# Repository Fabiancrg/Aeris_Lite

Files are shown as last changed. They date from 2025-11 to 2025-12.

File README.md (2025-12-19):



| Supported Targets | ESP32-C6 | ESP32-H2 |
| --- |  --- | --- |

# Zigbee Air Quality Sensor - Aeris




This project implements a Zigbee Router that reads air quality sensors and exposes them as standard Zigbee sensor endpoints with **real-time RGB LED visual indicators**.

## Key Features

✅ **7 Zigbee Endpoints**: Temperature, Humidity, Pressure, VOC Index, NOx Index, CO2, LED Config, Status LED  
✅ **4 High-Precision Sensors**: SHT45, LPS22HB, SGP41, SCD40  
✅ **4 RGB Status LEDs**: Independent visual feedback for CO2, VOC, NOx, and Humidity  
✅ **Configurable Thresholds**: Adjust warning/danger levels via Zigbee2MQTT  
✅ **Zigbee Router**: Can accept other devices (max 10 children)  
✅ **OTA Support**: Firmware updates over Zigbee  
✅ **Factory Reset**: Boot button for easy network reset

## Hardware Requirements

- ESP32-C6 development board (or compatible)
- Air quality sensors:
  - **SHT45 Temperature and Humidity sensor** via I2C
  - **LPS22HB Pressure sensor** via I2C
  - **SGP41 VOC and NOx sensor** via I2C
  - **SCD40 CO2 sensor** via I2C
- **5× SK6812/WS2812B RGB LEDs** in daisy-chain configuration (air quality visual indicators)
  - Single GPIO20 with SN74AHCT1G125 buffer for all LEDs
  - LED chain: CO2 → VOC → NOx → Humidity → Status
- I2C connection (SDA/SCL pins configurable)
- **Power supply**: 5V USB, 500mA minimum recommended

## Features

The Zigbee air quality sensor exposes the following sensor endpoints:

### Endpoint 1: Temperature and Humidity Sensor
- **Temperature Measurement Cluster (0x0402)**: Temperature in °C
- **Relative Humidity Measurement Cluster (0x0405)**: Humidity in %
- **Sensor**: Sensirion SHT45 (I2C)
- **Temperature Range**: -40°C to +125°C
- **Temperature Accuracy**: ±0.1°C (typical, 15-40°C)
- **Humidity Range**: 0-100% RH
- **Humidity Accuracy**: ±1.0% RH (typical, 25-75% RH)
- **Measurement Time**: 8.2ms (high precision mode)
- **Conversion**: Temperature: T = -45 + 175×(S/65535), Humidity: RH = -6 + 125×(S/65535)
- **Calibration Offsets**: Custom attributes (0xF010, 0xF011) for temperature/humidity adjustment
- **Sensor Refresh Interval**: Configurable update rate (10-3600s, default 30s) via attribute 0xF012

### Endpoint 2: Pressure Sensor
- **Pressure Measurement Cluster (0x0403)**: Atmospheric pressure in hPa
- **Sensor**: STMicroelectronics LPS22HB (I2C)
- **Update Rate**: On-demand (one-shot mode for power savings)
- **Range**: 260-1260 hPa
- **Accuracy**: ±0.025 hPa (typical)
- **Measurement Time**: ~15ms per reading

### Endpoint 3: VOC Index Sensor
- **Analog Input Cluster (0x000C)**: VOC Index (1-500)
- **Sensor**: Sensirion SGP41 (I2C)
- **Description**: Volatile Organic Compounds air quality index
- **Raw signals**: VOC raw values available
- **Update Rate**: 1 Hz enforced (minimum 1-second interval per datasheet)
- **Note**: Requires temperature/humidity compensation from SHT45

### Endpoint 4: NOx Index Sensor
- **Analog Input Cluster (0x000C)**: NOx Index (1-500)
- **Sensor**: Sensirion SGP41 (I2C)
- **Description**: Nitrogen Oxides air quality index
- **Raw signals**: NOx raw values available
- **Update Rate**: 1 Hz enforced (minimum 1-second interval per datasheet)
- **Note**: Requires temperature/humidity compensation from SHT45

### Endpoint 5: CO2 Sensor
- **CO2 Concentration Cluster (0x040D)**: Carbon dioxide in ppm
- **Sensor**: Sensirion SCD40 (I2C)
- **Range**: 400-2000 ppm (optimized for indoor air quality)
- **Accuracy**: ±(40 ppm + 5% of reading)
- **Update Rate**: 5 seconds (automatic periodic measurement)
- **Pressure Compensation**: Automatic compensation using LPS22HB pressure data
- **Calibration**: Automatic self-calibration (ASC) disabled for stable baseline in controlled environments
- **Additional**: Built-in temperature and humidity sensor (bonus)

### Endpoint 6: LED Configuration
- **On/Off Cluster (0x0006)**: Master switch to enable/disable all RGB status LEDs
- **Custom Attributes (0xF000-0xF00C)**: Configurable air quality thresholds and individual LED control
- **Bitmask Control (0xF00C)**: Individual enable/disable for each of the 4 LEDs
- **Thresholds**: Adjustable orange/red warning levels for VOC, NOx, CO2, Humidity

### Endpoint 7: Status LED
- **On/Off Cluster (0x0006)**: Enable/disable Zigbee status LED
- **Automatic Status Indication**: Shows Zigbee network connection status
  - 🟢 **Green**: Successfully connected to coordinator
  - 🟡 **Blinking Green/Orange**: Joining network
  - 🟠 **Orange**: Not joined to network
  - 🔴 **Red**: Error during initialization
- **GPIO**: GPIO8 (built-in LED on ESP32-C6 Supermini)

### RGB LED Air Quality Indicators

The device includes **4 separate RGB LEDs (SK6812)** that provide real-time visual feedback for air quality:

### LED Indicators
- **CO2 LED** (GPIO1): Shows carbon dioxide level status
- **VOC LED** (GPIO18): Shows volatile organic compounds status
- **NOx LED** (GPIO15): Shows nitrogen oxides status
- **Humidity LED** (GPIO14): Shows humidity level status

### Color Coding
Each LED independently displays:
- 🟢 **Green**: Parameter is in good/healthy range
- 🟠 **Orange**: Parameter is not ideal (warning level)
- 🔴 **Red**: Parameter is poor/unhealthy (danger level)

### Features
- **Independent operation**: Each LED shows only its corresponding sensor
- **At-a-glance status**: Quickly identify which parameter needs attention
- **Configurable thresholds**: Adjust warning/danger levels via Zigbee2MQTT
- **Brightness control**: Adjustable LED brightness (1-255) via Level Control cluster
- **Settings persistence**: All LED settings, thresholds, and calibrations stored in NVS (survive reboots)
- **Dual control**:
  - **Master switch**: Enable/disable all sensor LEDs at once (On/Off cluster)
  - **Individual control**: Enable/disable each LED separately via bitmask (0xF00C)
  - **Status LED control**: Independent on/off control for Zigbee status LED (endpoint 10)
- **Low power**: LEDs only update when color changes

### LED Control

**Master On/Off Switch:**
- Turn all LEDs on/off regardless of individual settings
- Located in On/Off cluster (standard Zigbee)

**Individual LED Bitmask (0xF00C):**
- Control each LED independently using a single 8-bit value
- Each bit represents one LED (1=enabled, 0=disabled)
- Bit assignments:
  - Bit 0 (0x01): CO2 LED
  - Bit 1 (0x02): VOC LED
  - Bit 2 (0x04): NOx LED
  - Bit 4 (0x10): Humidity LED
- Default: `0x17` (all LEDs enabled)

**Examples:**
```
0x17 (23)  - All LEDs enabled
0x03 (3)   - Only CO2 and VOC enabled
0x04 (4)   - Only NOx enabled
0x05 (5)   - CO2 and NOx enabled
0x00 (0)   - All LEDs disabled (individual level)
```

### Default Thresholds (all configurable)
- **VOC Index**: Orange ≥150, Red ≥250
- **NOx Index**: Orange ≥150, Red ≥250
- **CO2**: Orange ≥1000 ppm, Red ≥1500 ppm
- **Humidity**: Orange <30% or >70%, Red <20% or >80%

See [LED Configuration Guide](LED_CONFIGURATION.md) for detailed setup and usage.

## I2C and UART Configuration

### I2C Bus (Temperature, Humidity, Pressure, VOC, CO2)

The device communicates with most sensors via I2C:

- **SDA Pin**: GPIO 6 (configurable in `aeris_driver.h`)
- **SCL Pin**: GPIO 7 (configurable in `aeris_driver.h`)
- **Frequency**: 100 kHz
- **Pull-ups**: Internal pull-ups enabled

**I2C Addresses:**
- SHT45 (Temp/Humidity): 0x44 (fixed address)
- LPS22HB (Pressure): 0x5C (default, SA0=0) or 0x5D (SA0=1)
- SGP41 (VOC/NOx): 0x59 (fixed address)
- SCD40 (CO2): 0x62 (fixed address)

## Project Structure

```
Aeris_zb/
├── main/
│   ├── esp_zb_aeris.c         # Main Zigbee application
│   ├── esp_zb_aeris.h         # Zigbee configuration header
│   ├── aeris_driver.c         # Air quality sensor driver implementation
│   ├── aeris_driver.h         # Sensor driver header
│   ├── led_indicator.c        # RGB LED driver (6 LEDs via RMT)
│   ├── led_indicator.h        # LED driver header
│   ├── settings.c             # NVS settings persistence
│   ├── settings.h             # Settings header
│   ├── esp_zb_ota.c           # OTA update support
│   ├── esp_zb_ota.h           # OTA header
│   ├── board.h                # Board pin definitions (GPIO mapping)
│   ├── CMakeLists.txt         # Component build configuration
│   └── idf_component.yml      # Component dependencies
├── CMakeLists.txt             # Project CMakeLists
├── sdkconfig                  # ESP-IDF configuration
├── README.md                  # This file
├── LED_CONFIGURATION.md   # LED setup and Zigbee2MQTT integration
├── LED_IMPLEMENTATION.md  # LED technical implementation details
└── ENDPOINT_MAP.md        # Complete Zigbee endpoi
```

## Building and Flashing

1. Set up ESP-IDF v5.5.1 or later
2. Configure the project:
   ```bash
   idf.py set-target esp32c6
   idf.py menuconfig
   ```
3. Build the project:
   ```bash
   idf.py build
   ```
4. Flash to device:
   ```bash
   idf.py -p COMx flash monitor
   ```

## Configuration

### Zigbee Configuration

The device is configured as a Zigbee Router:
- **Endpoints**: 1-7 (sensor data + LED configuration + status LED)
  - Endpoints 1-5: Sensor data (Temperature, Humidity, Pressure, VOC, NOx, CO2)
  - Endpoint 6: Air quality LED configuration and control
  - Endpoint 7: Zigbee status LED control
- **Profile**: Home Automation (0x0104)
- **Device IDs**: Various sensor types + On/Off output for LED control
- **Channel Mask**: All channels
- **Max Children**: 10 (router can accept other devices)

### LED Configuration

**Air Quality LEDs (4 LEDs)** - Configure via Zigbee2MQTT endpoint 6:
- **Master On/Off**: Single switch to enable/disable all LEDs (On/Off cluster)
- **Individual Control**: Bitmask attribute (0xF00C) for per-LED enable/disable
  - Set to `0x17` (23) for all LEDs
  - Set to `0x03` (3) for CO2 + VOC only
  - Set to `0x00` (0) to disable all (at individual level)
- **Thresholds**: 8 configurable attributes (VOC, NOx, CO2, Humidity orange/red levels)
- **GPIO Pins**: Configurable in `main/board.h` (defaults: GPIO1, 18, 15, 14)

**Control Logic:**
- Master OFF → All LEDs off (ignores bitmask)
- Master ON + bit set → LED shows sensor status color
- Master ON + bit clear → LED off

**Zigbee Status LED (1 LED)** - Configure via Zigbee2MQTT endpoint 7:
- **On/Off Control**: Enable/disable status LED
- **Automatic Status Indication**:
  - 🟢 **Green**: Successfully connected to Zigbee coordinator
  - 🟡 **Blinking Green/Orange**: Actively joining network (searching for coordinator)
  -  **Orange**: Not joined to any network or left the network (idle)
  - 🔴 **Red**: Error during initialization or join failed
- **GPIO Pin**: GPIO23 (configurable in `main/board.h`)
- **Blink Pattern**: 500ms interval during network join process

See [LED Configuration Guide](LED_CONFIGURATION.md) for detailed threshold settings.

### Sensor Configuration

Configure sensor I2C addresses and settings in `aeris_driver.c`:
- Default I2C pins: SDA=GPIO6, SCL=GPIO7
- Adjust pins in `aeris_driver.h` if needed

### Joining the Network

On first boot, the device will automatically enter network steering mode. Once joined, the device will save the network credentials and automatically rejoin on subsequent boots.

## Usage

### From Zigbee Coordinator (e.g., Zigbee2MQTT, Home Assistant)

1. Put your coordinator in pairing mode
2. Power on the ESP32-C6 device
3. Wait for the device to join (check logs - status LED will turn green when connected)
4. The air quality sensor will appear with the following entities:
   - Temperature (°C)
   - Humidity (%)
   - Pressure (hPa)
   - VOC Index (1-500)
   - NOx Index (1-500)
   - CO2 (ppm)
   - **Air Quality LED Master Switch** (On/Off - controls all 4 air quality LEDs)
   - **LED Enable Mask** (0-15 - individual LED control)
   - **LED Thresholds** (configurable warning/danger levels)
   - **Status LED Switch** (On/Off - controls Zigbee status LED)

### LED Control Examples

**Via Zigbee2MQTT:**

```javascript
// Turn all sensor LEDs on (master switch)
await publish('zigbee2mqtt/aeris/set', {state: 'ON'});

// Turn all sensor LEDs off (master switch)
await publish('zigbee2mqtt/aeris/set', {state: 'OFF'});

// Set LED brightness (1-255, default 128)
await publish('zigbee2mqtt/aeris/set', {brightness: 128});
await publish('zigbee2mqtt/aeris/set', {brightness: 255});  // Max brightness
await publish('zigbee2mqtt/aeris/set', {brightness: 64});   // Dim

// Enable all 4 LEDs individually (bitmask)
await publish('zigbee2mqtt/aeris/set', {led_enable_mask: 15});  // 0x0F

// Enable only CO2 and VOC LEDs
await publish('zigbee2mqtt/aeris/set', {led_enable_mask: 3});   // 0x03

// Enable only NOx LED
await publish('zigbee2mqtt/aeris/set', {led_enable_mask: 4});   // 0x04

// Enable CO2, VOC, and Humidity LEDs
await publish('zigbee2mqtt/aeris/set', {led_enable_mask: 11});  // 0x0B

// Disable all LEDs via bitmask (master can still be ON)
await publish('zigbee2mqtt/aeris/set', {led_enable_mask: 0});

// Status LED control (endpoint 10)
await publish('zigbee2mqtt/aeris_status/set', {state: 'ON'});   // Enable status LED
await publish('zigbee2mqtt/aeris_status/set', {state: 'OFF'});  // Disable status LED

// Calibration offsets (stored in NVS)
await publish('zigbee2mqtt/aeris/set', {temperature_offset: 5});   // +0.5°C
await publish('zigbee2mqtt/aeris/set', {temperature_offset: -10}); // -1.0°C
await publish('zigbee2mqtt/aeris/set', {humidity_offset: 20});     // +2.0% RH

// Sensor refresh interval (10-3600 seconds, default 30)
await publish('zigbee2mqtt/aeris/set', {sensor_refresh_interval: 60}); // 1 minute
```

### Visual LED Status

**Air Quality LEDs (4 RGB LEDs)** provide real-time visual feedback:
- **CO2 LED**: Green/Orange/Red based on CO2 levels
- **VOC LED**: Green/Orange/Red based on VOC Index
- **NOx LED**: Green/Orange/Red based on NOx Index
- **Humidity LED**: Green/Orange/Red based on humidity range

**Status LED (1 RGB LED)** shows Zigbee network state:
- 🟢 **Green**: Connected to coordinator
- 🟡 **Blinking Green/Orange**: Joining network (searching)
- 🟠 **Orange**: Not joined or left network (idle)
- 🔴 **Red**: Join failed or error state (will retry)

**At a glance**, you can see:
- All green (air quality) = Excellent air quality
- Mixed colors = Some parameters need attention
- Status LED solid green = Device is online and connected
- Status LED blinking = Device is trying to join network
- Red LEDs = Immediate action needed (ventilate, increase/decrease humidity, etc.)

Configure thresholds in Zigbee2MQTT to match your preferences. See [LED Configuration Guide](LED_CONFIGURATION.md).

### Sensor Reading Updates

- Sensors are polled periodically (configurable interval)
- Values are reported to the Zigbee coordinator when they change
- All endpoints support binding and reporting configuration

## Supported Sensors

This project provides a framework for air quality sensors. You'll need to implement the actual sensor drivers:

### Temperature/Humidity
- **SHT45** (implemented): Sensirion high-precision sensor
  - I2C interface (address 0x44)
  - Temperature: -40 to +125°C, ±0.1°C accuracy
  - Humidity: 0-100% RH, ±1.0% RH accuracy
  - High repeatability mode: 8.2ms measurement time
  - CRC-8 checksum for data integrity
  - Serial number readout
  - Soft reset command
  - Low power: 0.4 µA idle
- **Alternative**: SHT4x series, BME280, DHT22

### Pressure
- **LPS22HB** (implemented): STMicroelectronics MEMS pressure sensor
  - I2C interface (address 0x5C or 0x5D)
  - Measures 260-1260 hPa
  - ±0.025 hPa accuracy
  - Internal temperature sensor (bonus)
  - Low power: 3 µA @ 1Hz
  - Configurable output rate (1-75 Hz)
- **Alternative**: BMP280, BME280 (Bosch sensors)

### VOC and NOx Index
- **SGP41** (implemented): Sensirion VOC and NOx sensor
  - I2C interface (address 0x59)
  - Dual gas sensing: VOC + NOx
  - Separate Zigbee endpoints for VOC (endpoint 6) and NOx (endpoint 7)
  - Raw signal output (requires algorithm)
  - Temperature/humidity compensation
  - Built-in heater for measurement
  - Low power: 2.6 mA average @ 1Hz
  - Serial number readout
  - Self-test capability
- **Note**: Full Gas Index Algorithm integration recommended for production
- **Alternative**: SGP40 (VOC only), BME680 (combo sensor)

### CO2
- **SCD40** (implemented): Sensirion NDIR CO2 sensor
  - I2C interface (address 0x62)
  - Range: 400-2000 ppm (indoor air quality)
  - Accuracy: ±(40 ppm + 5%)
  - Automatic periodic measurement every 5 seconds
  - **Ambient pressure compensation** from LPS22HB sensor
  - Built-in temperature and humidity sensor
  - Automatic self-calibration (ASC)
  - CRC-8 data validation
  - Serial number readout
  - Low power: 15 mA average @ 1 measurement/5s
- **Alternative**: SCD41 (extended range 400-5000 ppm)

## Implementation Notes

The `aeris_driver.c` file contains:

1. **SHT45 implementation** (complete):
   - I2C initialization and device detection
   - Soft reset on startup
   - Serial number readout and verification
   - High repeatability measurement mode
   - CRC-8 validation on all data
   - Temperature and humidity conversion
   - Humidity clamping to 0-100% range

2. **LPS22HB implementation** (complete):
   - I2C initialization and device detection
   - WHO_AM_I verification (0xB1)
   - 25 Hz output data rate
   - Block data update enabled
   - Pressure reading in hPa
   - Temperature reading included

4. **SGP41 implementation** (complete):
   - I2C initialization and device detection
   - Serial number readout and verification
   - Self-test execution
   - Raw VOC and NOx signal measurement
   - Separate VOC and NOx index reporting (endpoints 6 and 7)
   - Temperature/humidity compensation support
   - CRC8 validation on all data
   - Placeholder index calculation (needs Gas Index Algorithm)

5. **SCD40 implementation** (complete):
   - I2C initialization and device detection
   - Serial number readout and verification
   - Automatic periodic measurement mode
   - CO2, temperature, and humidity reading
   - Ambient pressure compensation using LPS22HB data
   - CRC-8 validation on all data
   - Data ready status checking
   - 5-second measurement interval

## Sensor Wiring Diagrams

### SHT45 Wiring

```
SHT45 Pin → ESP32-C6
VDD       → 3.3V
GND       → GND
SCL       → GPIO 7
SDA       → GPIO 6
```

**Note**: SHT45 operates at 3.3V. No level shifters needed with ESP32-C6.

### LPS22HB Wiring

```
LPS22HB Pin → ESP32-C6
VDD         → 3.3V
GND         → GND
SCL         → GPIO 7 (I2C SCL)
SDA         → GPIO 6 (I2C SDA)
SA0         → GND (for address 0x5C) or 3.3V (for 0x5D)
```

**Note**: LPS22HB operates at 1.7-3.6V. Use 3.3V supply.

### SGP41 Wiring

```
SGP41 Pin → ESP32-C6
VDD       → 3.3V
GND       → GND
SCL       → GPIO 7 (I2C SCL)
SDA       → GPIO 6 (I2C SDA)
```

**Note**: SGP41 operates at 1.7-3.6V. Use 3.3V supply. No external pull-ups needed on most breakout boards.

### SCD40 Wiring

```
SCD40 Pin → ESP32-C6
VDD       → 3.3V
GND       → GND
SCL       → GPIO 7 (I2C SCL)
SDA       → GPIO 6 (I2C SDA)
```

**Note**: SCD40 operates at 2.4-5.5V. Use 3.3V supply. Automatic periodic measurement every 5 seconds. Benefits from ambient pressure compensation provided by LPS22HB sensor.

### SK6812 RGB LED Wiring (5 LEDs)

The device uses 5 separate RGB LEDs for visual air quality feedback:

```
LED Purpose    GPIO    Connection
━━━━━━━━━━━━━━━━━━━━━━━━━━━━━━━━━━━━━━━
CO2 LED        1       Data line
VOC LED        18      Data line
NOx LED        15      Data line
Humidity LED   14      Data line
Status LED     8       Data line (Zigbee status)

For each LED:
  Data → GPIO pin (see table above)
  VCC  → 5V (SK6812 specification)
  GND  → GND
```

**Notes**: 
- SK6812 LEDs use WS2812 protocol via RMT peripheral
- Each LED operates independently showing its sensor's status
- All 5 sensor LEDs can be enabled/disabled together via Zigbee (endpoint 9)
- Status LED controlled separately via endpoint 10
- Brightness adjustable 1-255 via Level Control cluster
- GPIO pins are configurable in `main/board.h`
- Total LED current (all 6 at max brightness): ~360mA

**Color Codes**:
- 🟢 Green = Good air quality for that parameter
- 🟠 Orange = Warning level (not ideal)
- 🔴 Red = Danger level (poor air quality)

See [LED Configuration Guide](LED_CONFIGURATION.md) for threshold configuration via Zigbee2MQTT.

### Important: Gas Index Algorithm

The SGP41 currently uses a **simplified placeholder** for VOC/NOx index calculation. For production use, integrate Sensirion's **Gas Index Algorithm**:

- Download from: https://github.com/Sensirion/gas-index-algorithm
- Provides proper VOC Index (1-500) and NOx Index (1-500)
- Requires learning period (~10 minutes for VOC, ~12 hours for NOx)
- Handles baseline tracking and auto-calibration

## Troubleshooting

### Sensors not responding
- **I2C sensors**:
  - Verify I2C wiring (SDA/SCL connections)
  - Check I2C pull-up resistors (usually 4.7kΩ)
  - Verify sensor power supply (3.3V for SHT45, LPS22HB, SGP41, SCD40)
  - Use `i2cdetect` to scan for sensor addresses
  - Monitor I2C traffic in logs
  - **SHT45**: Read serial number to verify communication
  - **SHT45**: Check CRC errors in logs
  - **LPS22HB**: Check WHO_AM_I register (should be 0xB1)
  - **LPS22HB**: Verify address 0x5C or 0x5D (depends on SA0 pin)
  - **SGP41**: Check serial number readout
  - **SGP41**: Verify self-test passes (result 0xD400)
  - **SGP41**: Ensure temperature/humidity data is available for compensation
  - **SCD40**: Check serial number readout
  - **SCD40**: Verify data ready status (measurements every 5 seconds)
  - **SCD40**: Check CRC errors in logs

**Power Note**: 
- **5 LEDs** (4 air quality + 1 status) at full brightness: ~300mA
- **ESP32-C6 + sensors**: ~50-80mA
- **Total**: ~350-380mA
- **Recommended power supply**: 500mA minimum (USB 5V)

### Build errors
- Make sure ESP-IDF v5.5.1+ is installed
- Run `idf.py fullclean` and rebuild
- Check that all sensor libraries are in `idf_component.yml`

---

## 🙌 Credits

- Zigbee2MQTT ecosystem: [Koenkk/zigbee2mqtt](https://github.com/Koenkk/zigbee2mqtt) and [zigbee-herdsman-converters](https://github.com/Koenkk/zigbee-herdsman-converters)
- Base Zigbee framework: Espressif ESP-IDF examples

## 🛡️ License

This repository uses multiple licenses depending on content type:

- **Code** (`*.c`, `*.h`, `*.yaml`) — [GNU GPLv3](./LICENSE)  
- **PCB files** (`*.zip`, `*.json`) — [CC BY-NC-SA 4.0](./LICENSE-hardware)

---

## ⚠️ Disclaimer

This project is provided as-is, without any warranty or guarantee of fitness for a particular purpose. Use at your own risk. The authors and contributors are not responsible for any damage, malfunction, or loss resulting from the use, modification, or installation of this hardware or software.

- This is an open-source, community-driven project intended for educational and experimental use.
- The hardware and firmware are not certified for commercial or safety-critical applications.
- Always follow proper electrical safety procedures when working with sensors and embedded systems.
- Modifying or installing this project may void your equipment warranty.
- Ensure compliance with local laws and regulations regarding wireless devices.

By using this project, you acknowledge and accept these terms.

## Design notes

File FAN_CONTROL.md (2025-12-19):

# Fan Control System - Aeris Lite

## Overview

The Aeris Lite includes an intelligent fan control system to improve sensor accuracy by managing airflow across the sensors. This is especially important because some sensors (SGP41, SCD40) generate heat during operation which can affect temperature and humidity readings.

## Hardware Setup

### Components Required

- **Fan**: 5V 4-wire PWM fan (25mm, 30mm, or 40mm)
  - Recommended: Dual ball bearing type for reliability
  - Example: Sunon MF25100V1-1000U-A99 or similar
- **MOSFET**: IRLML6344TRPBF (N-channel, SOT-23)
- **Diode**: N5819HW1-7-F (1A Schottky, SOD-123)
- **Resistor**: 10kΩ (0603/0805 SMD)

### Circuit Diagram

```
              5V Supply
                 │
              [Fan Motor]
                 │
         ┌──[N5819HW1-7-F]──┐  Flyback protection diode
         │   (Schottky)      │  (Cathode to 5V, Anode to Drain)
         │                   │
    [Drain]                  │
         │                   │
   IRLML6344TRPBF            │
         │                   │
    [Gate]────[10kΩ]─────────┘  Pull-down resistor
         │                   
GPIO5 (3.3V)                   Power control
         │                   
    [Source]                 
         │                   
        GND                  

Fan 4-Wire Connections:
  Red/Yellow → 5V (through MOSFET)
  Black      → GND
  Blue       → GPIO6 (PWM speed control)
  Yellow     → GPIO7 (TACH feedback)
```

### GPIO Pin Assignments

| Function | GPIO | Direction | Description |
|---|---|---|---|
| Fan Power | GPIO5 | Output | N-MOSFET gate (ON/OFF control) |
| Fan PWM | GPIO6 | Output | PWM signal (25kHz, 0-100% duty) |
| Fan TACH | GPIO7 | Input | Tachometer pulses (RPM monitoring) |

## Features

### 1. PWM Speed Control
- **Frequency**: 25kHz (standard for PC fans)
- **Resolution**: 8-bit (0-255 duty cycle)
- **Speed Range**: 0-100%
- **Minimum Speed**: 20% (fans typically don't start below this)

### 2. RPM Monitoring
- Real-time RPM measurement via tachometer
- 2 pulses per revolution (standard)
- Blocking measurement (~1 second)
- Health monitoring and fault detection

### 3. Operating Modes
- **OFF** (0%): Fan completely stopped
- **LOW** (30%): Quiet operation, minimal airflow
- **MEDIUM** (60%): Balanced airflow and noise
- **HIGH** (100%): Maximum airflow
- **AUTO**: Adaptive speed based on sensor readings

### 4. Adaptive Control
Automatically adjusts fan speed based on:
- **Temperature**: Higher temps → faster fan
- **VOC Index**: Poor air quality → faster fan
- **Thresholds**:
  - T > 35°C or VOC > 300 → HIGH (100%)
  - T > 30°C or VOC > 200 → MEDIUM (60%)
  - T > 25°C or VOC > 150 → LOW (30%)
  - Otherwise → OFF (0%)

### 5. Health Monitoring
- Detects fan stall/failure (RPM < 100)
- Verifies fan starts when commanded
- Can trigger alerts or fallback behavior

## Software API

### Initialization

```c
#include "fan_control.h"

// Initialize fan control (call once at startup)
esp_err_t ret = fan_init();
if (ret != ESP_OK) {
    ESP_LOGE("APP", "Fan init failed");
}
```

### Basic Control

```c
// Set fan speed (0-100%)
fan_set_speed(50);  // 50% speed

// Power control
fan_set_power(true);   // Turn on
fan_set_power(false);  // Turn off

// Predefined modes
fan_set_mode(FAN_MODE_LOW);     // 30%
fan_set_mode(FAN_MODE_MEDIUM);  // 60%
fan_set_mode(FAN_MODE_HIGH);    // 100%
fan_set_mode(FAN_MODE_OFF);     // 0%
```

### RPM Monitoring

```c
// Get current RPM (blocks for ~1 second)
uint32_t rpm = fan_get_rpm();
ESP_LOGI("APP", "Fan RPM: %lu", rpm);

// Quick check (uses last reading)
bool running = fan_is_running();
if (!running) {
    ESP_LOGW("APP", "Fan not running!");
}

// Get full status
fan_status_t status;
fan_get_status(&status);
ESP_LOGI("APP", "Enabled: %d, Speed: %d%%, RPM: %lu, Running: %d, Fault: %d",
         status.enabled, status.speed_percent, status.rpm, 
         status.running, status.fault);
```

### Advanced: Adaptive Control

```c
// In your main measurement loop:
void sensor_measurement_task(void *pvParameters) {
    while (1) {
        float temp = read_temperature();
        uint16_t voc = read_voc_index();
        
        // Automatically adjust fan speed
        fan_adaptive_control(temp, voc);
        
        vTaskDelay(pdMS_TO_TICKS(30000));  // Every 30s
    }
}
```

### Health Check Example

```c
// Set speed and verify fan starts
esp_err_t ret = fan_control_with_check(60);
if (ret == ESP_FAIL) {
    ESP_LOGE("APP", "Fan failed to start - check hardware!");
    // Could trigger alarm, LED indicator, etc.
}
```

## Integration with Aeris Driver

The fan control is automatically initialized in `aeris_driver_init()` and starts at low speed (30%) by default. This provides continuous gentle airflow for accurate sensor readings while keeping noise low.

To enable adaptive control, modify your measurement loop:

```c
aeris_sensor_state_t state;
aeris_get_sensor_data(&state);

// Adaptive fan control based on readings
fan_adaptive_control(state.temperature_c, state.voc_index);
```

## Zigbee Integration (Future Enhancement)

The fan control can be exposed via Zigbee custom attributes:

```c
/* Proposed custom attributes for fan control */
#define ATTR_FAN_ENABLED      0xF030  // bool - Fan power ON/OFF
#define ATTR_FAN_SPEED        0xF031  // uint8 - Speed percentage (0-100)
#define ATTR_FAN_MODE         0xF032  // uint8 - Mode (0=OFF, 1=LOW, 2=MED, 3=HIGH, 4=AUTO)
#define ATTR_FAN_RPM          0xF033  // uint32 - Current RPM (read-only)
#define ATTR_FAN_STATUS       0xF034  // uint8 - Status (0=Off, 1=Running, 2=Fault)
```

This would allow control via Home Assistant/Zigbee2MQTT:
- Enable/disable fan remotely
- Adjust speed percentage
- Select operating mode
- Monitor RPM and health status

## Troubleshooting

### Fan Doesn't Start
1. Check 5V power supply (adequate current)
2. Verify GPIO connections (GPIO5, GPIO6, GPIO7)
3. Check MOSFET soldering (IRLML6344TRPBF)
4. Verify diode polarity (N5819HW1-7-F)
5. Try higher speed: `fan_set_speed(50)` or more
6. Check fan minimum starting speed (usually 20-30%)

### Fan Runs But No RPM Reading
1. Verify TACH wire connected to GPIO7
2. Check pull-up enabled (automatic in code)
3. Confirm fan has 4 wires (TACH output)
3-wire fans don't have TACH
4. Try different fan (some cheap fans have fake TACH)

### Fan Too Noisy
1. Reduce speed: `fan_set_speed(30)` or lower
2. Check fan quality (dual ball bearing are quieter long-term)
3. Verify fan is mounted securely (vibration causes noise)
4. Consider larger fan at lower RPM (40mm vs 25mm)

### Sensors Still Show Self-Heating
1. Increase fan speed: `fan_set_speed(60)`
2. Check airflow path (ensure air reaches sensors)
3. Verify fan is drawing air across sensors
4. Use temperature offset calibration (existing feature)
5. Consider enclosure ventilation holes

### Fan Runs at Full Speed Always
1. Check PWM wire connected to GPIO6 (not 5V)
2. Verify fan supports PWM control (4-wire)
3. Check PWM signal with oscilloscope (25kHz)
4. Try different GPIO if interference suspected

## Power Consumption

| Mode | Fan Speed | Typical Current | Power |
|---|---|---|---|
| OFF | 0% | 0mA | 0W |
| LOW | 30% | 40-60mA | 0.2-0.3W |
| MEDIUM | 60% | 80-100mA | 0.4-0.5W |
| HIGH | 100% | 120-150mA | 0.6-0.75W |

**Note**: Power consumption varies by fan model. Larger fans draw more current.

## PCB Layout Recommendations

1. **Trace widths**: 
   - 5V power to fan: 20-30 mil (0.5-0.76mm)
   - GPIO signals: 10 mil (0.25mm) minimum
   
2. **Component placement**:
   - Place MOSFET and diode close to fan connector
   - Keep PWM trace short to reduce EMI
   
3. **Ground plane**: 
   - Connect MOSFET source directly to ground plane
   - Use thermal relief for easy soldering
   
4. **Thermal considerations**:
   - No heatsink needed for IRLML6344TRPBF (<1mW dissipation)
   - Keep away from hot components if possible

## Performance Impact

### With Fan (Recommended)
- ✅ Temperature accuracy: ±0.2°C
- ✅ Humidity accuracy: ±1%RH
- ✅ Fast response time (<30s)
- ✅ Representative sampling
- ⚠️ Additional power: ~0.2-0.5W
- ⚠️ Slight noise (dependent on speed)

### Without Fan
- ⚠️ Temperature error: +2-4°C (self-heating)
- ⚠️ Humidity affected by temperature error
- ⚠️ Slow response time (>2 min)
- ⚠️ Stagnant air (non-representative)
- ✅ Lower power consumption
- ✅ Silent operation

## Conclusion

The fan control system significantly improves sensor accuracy for the Aeris Lite by managing self-heating effects and ensuring representative air sampling. The adaptive control automatically balances performance, accuracy, and noise based on environmental conditions.

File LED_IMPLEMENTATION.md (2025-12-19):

# RGB LED Implementation Summary

## Overview
Successfully implemented **5 SK6812/WS2812B RGB LEDs in daisy-chain configuration** on a single GPIO with configurable air quality thresholds via Zigbee2MQTT. Each sensor parameter (CO2, VOC, NOx, Humidity) has its own dedicated LED indicator, plus a separate **status LED** for network/firmware state.

## Architecture Changes (v2.0)

### Hardware Simplification
**Previous (v1.0):** 5 separate GPIOs (GPIO1, GPIO18, GPIO15, GPIO14, GPIO8) with 74AHCT244 driver
**Current (v2.0):** Single GPIO20 with SN74AHCT1G125 buffer, 5 LEDs in daisy-chain

**Benefits:**
- Saves 4 GPIOs for other peripherals
- Simpler PCB routing (single data line)
- More efficient RMT usage (1 channel instead of 5)
- Synchronized LED updates (all LEDs refresh at once)
- Single point buffer/level shifter

### LED Daisy-Chain Order
```
GPIO20 → Buffer → [CO2] → [VOC] → [NOx] → [Humidity] → [Status]
                   Pos0     Pos1    Pos2      Pos3         Pos4
```

## Files Created/Modified

### New Files
1. **main/led_indicator.h** - LED driver API for 6 independent LEDs
2. **main/led_indicator.c** - SK6812 RMT driver with 6-channel support
3. **doc/LED_CONFIGURATION.md** - Complete user documentation for LED configuration

### Modified Files
1. **main/board.h** - Added 6 LED GPIO pin definitions:
   - CO2: GPIO21
   - VOC: GPIO4
   - NOx: GPIO8
   - PM2.5: GPIO5
   - Humidity: GPIO10
   - Status: GPIO23 (network/firmware status indicator)
2. **main/esp_zb_aeris.h** - Added:
   - LED configuration endpoint (endpoint 8)
   - 12 custom attribute IDs for thresholds (0xF000-0xF00B)
3. **main/esp_zb_aeris.c** - Added:
   - LED driver include
   - LED initialization in deferred_driver_init()
   - Endpoint 8 creation with On/Off + custom threshold attributes
   - Attribute handler for LED configuration changes
   - LED update call in sensor_update_zigbee_attributes()
4. **main/CMakeLists.txt** - Added esp_driver_rmt dependency

## Features Implemented

### Hardware
- **6 separate SK6812 RGB LEDs** using ESP32-C6 RMT peripheral
- Each LED on dedicated GPIO (GPIO21, GPIO4, GPIO8, GPIO5, GPIO10, GPIO23)
- **6 independent RMT channels** for simultaneous control (5 parameter LEDs + 1 status)
- Three color states per LED: Green (good), Orange (warning), Red (danger)
- Efficient RMT encoding for precise SK6812 timing

### Zigbee Integration
- **Endpoint 8**: LED Configuration
   - **Single On/Off cluster** for global enable/disable of all parameter LEDs (CO2, VOC, NOx, PM2.5, Humidity)
   - Analog Output cluster containing 12 custom threshold attributes
   - All parameter thresholds configurable via Zigbee2MQTT

### Threshold Parameters
All configurable via Zigbee attributes:

**VOC Index:**
- Orange threshold: 150 (default)
- Red threshold: 250 (default)

**CO2 (ppm):**
- Orange threshold: 1000 (default)
- Red threshold: 1500 (default)

**Humidity (%):**
- Orange low: 30% (default) - too dry warning
- Orange high: 70% (default) - too humid warning
- Red low: 20% (default) - too dry danger
- Red high: 80% (default) - too humid danger

**PM2.5 (µg/m³):**
- Orange threshold: 25 (default)
- Red threshold: 55 (default)

**NOx (ppb):**
- Orange threshold: 200 (default)
- Red threshold: 400 (default)

### LED Behavior
- **Each sensor has its own dedicated LED** showing independent status
- Evaluates sensors every 30 seconds
- **CO2 LED**: Shows CO2 level (green/orange/red based on CO2 thresholds)
- **VOC LED**: Shows VOC Index (green/orange/red based on VOC thresholds)
- **NOx LED**: Shows NOx level (green/orange/red based on NOx thresholds)
- **PM2.5 LED**: Shows particulate matter (green/orange/red based on PM2.5 thresholds)
- **Humidity LED**: Shows humidity level (green/orange/red based on humidity thresholds)
- **Status LED**: Shows network/firmware status (joining, connected, error) — behavior controlled by firmware, not thresholds
- **Single On/Off control** disables/enables all parameter LEDs; the status LED may remain active for critical network indicators depending on configuration
- Only updates each LED when its color changes (reduces RMT traffic)

## Default Thresholds Rationale

### VOC Index (Sensirion SGP41)
- 0-150: Good air quality → **Green**
- 151-250: Moderate, not ideal → **Orange**
- 251-500: Poor air quality → **Red**

### CO2 Levels
- 400-1000 ppm: Normal indoor → **Green**
- 1001-1500 ppm: Needs ventilation → **Orange**
- 1501+ ppm: Poor ventilation → **Red**

### Humidity
- 30-70%: Comfort zone → **Green**
- 20-30% or 70-80%: Outside comfort → **Orange**
- <20% or >80%: Health/mold risk → **Red**

### PM2.5 (EPA AQI)
- 0-25 µg/m³: Good/Moderate → **Green**
- 26-55 µg/m³: Unhealthy for sensitive → **Orange**
- 56+ µg/m³: Unhealthy → **Red**

## Usage Example

### From Zigbee2MQTT:
```json
# Enable all LEDs
{"led_enabled": true}

# Disable all LEDs
{"led_enabled": false}

# Adjust CO2 thresholds for stricter monitoring
{"co2_orange_threshold": 800, "co2_red_threshold": 1200}

# Make humidity range wider (20-75% before warning)
{"humidity_orange_low": 20, "humidity_orange_high": 75}
```

### In Home Assistant:
All thresholds appear as `number` entities. The single `switch.aeris_led_enabled` controls all parameter LEDs together (CO2, VOC, NOx, PM2.5, Humidity); the status LED behavior is firmware-controlled.

### LED Status Display:
With 4 separate LEDs, you can see the status of all parameters at a glance:
- All green = Excellent air quality across all parameters
- Mixed colors = Some parameters need attention
- Individual LED shows specific problem (e.g., red CO2 LED = ventilation needed)

## Testing Checklist
- [ ] Build project with `idf.py build`
- [ ] Flash to ESP32-C6
- [ ] Verify all 6 LEDs initialize (check serial logs)
- [ ] Pair with Zigbee coordinator
- [ ] Check that endpoint 8 appears in Zigbee2MQTT
- [ ] Test enabling/disabling all LEDs via On/Off attribute
- [ ] Adjust thresholds and verify appropriate LED changes color
- [ ] Test all 4 sensor thresholds independently:
  - [ ] VOC LED changes when VOC Index crosses thresholds
  - [ ] CO2 LED changes when CO2 crosses thresholds
  - [ ] Humidity LED changes when humidity crosses thresholds
  - [ ] PM2.5 LED changes when PM2.5 crosses thresholds
- [ ] Verify each LED operates independently

## Troubleshooting

**LEDs don't light:**
- Check GPIO wiring (GPIO21, GPIO4, GPIO8, GPIO5, GPIO10, GPIO23)
- Verify LED power supply for all 4 LEDs
- Check serial logs for RMT initialization errors
- Ensure LEDs are enabled (On/Off = true)

**Only some LEDs work:**
- Check individual GPIO connections
- Verify all 4 RMT channels initialized in logs
- Test each LED individually

**Can't change thresholds:**
- Verify endpoint 8 is exposed in Zigbee2MQTT
- Check custom attribute IDs are mapped correctly
- Try re-pairing device

**Wrong colors displayed:**
- Verify sensor readings are accurate (check sensor endpoints)
- Review threshold configuration for specific sensor
- Check logs for individual LED update messages

## Next Steps
1. Build and flash firmware
2. **Connect 4 SK6812 LEDs:**
   - CO2 LED → GPIO21
   - VOC LED → GPIO4
   - PM2.5 LED → GPIO5
   - Humidity LED → GPIO10
3. Pair with Zigbee coordinator
4. Configure thresholds in Zigbee2MQTT/Home Assistant
5. Fine-tune thresholds based on your environment
6. Observe each LED independently showing sensor status

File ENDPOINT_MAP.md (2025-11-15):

# Aeris_zb Endpoint Map

## Complete Endpoint Structure

```
┌─────────────────────────────────────────────────────────────────┐
│                     Aeris Air Quality Sensor                     │
│                      (Zigbee Router Device)                      │
└─────────────────────────────────────────────────────────────────┘

Endpoint 1: Temperature & Humidity
├─ Temperature Measurement (0x0402)
│  └─ Measured Value (int16, 0.01°C units)
├─ Relative Humidity Measurement (0x0405)
│  └─ Measured Value (uint16, 0.01% units)
└─ Basic, Identify clusters

Endpoint 2: Pressure
├─ Pressure Measurement (0x0403)
│  └─ Measured Value (int16, 0.1 hPa units)
└─ Basic, Identify clusters

Endpoint 3: PM1.0
├─ Analog Input (0x000C)
│  ├─ Present Value (float, µg/m³)
│  └─ Description: "PM1.0 µg/m³"
└─ Basic, Identify clusters

Endpoint 4: PM2.5
├─ Analog Input (0x000C)
│  ├─ Present Value (float, µg/m³)
│  └─ Description: "PM2.5 µg/m³"
└─ Basic, Identify clusters

Endpoint 5: PM10
├─ Analog Input (0x000C)
│  ├─ Present Value (float, µg/m³)
│  └─ Description: "PM10 µg/m³"
└─ Basic, Identify clusters

Endpoint 6: VOC Index
├─ Analog Input (0x000C)
│  ├─ Present Value (float, 1-500 index)
│  └─ Description: "VOC Index"
└─ Basic, Identify clusters

Endpoint 7: CO2
├─ Carbon Dioxide Measurement (0x040D)
│  ├─ Measured Value (float, ppm)
│  ├─ Min Measured Value: 400
│  └─ Max Measured Value: 5000
└─ Basic, Identify clusters

Endpoint 8: LED Configuration
├─ On/Off (0x0006)
│  └─ OnOff (bool) - Enable/disable LED
├─ Analog Output (0x000D) - Container for custom attributes
│  ├─ 0xF000: VOC Orange Threshold (uint16)
│  ├─ 0xF001: VOC Red Threshold (uint16)
│  ├─ 0xF002: CO2 Orange Threshold (uint16)
│  ├─ 0xF003: CO2 Red Threshold (uint16)
│  ├─ 0xF004: Humidity Orange Low (uint16)
│  ├─ 0xF005: Humidity Orange High (uint16)
│  ├─ 0xF006: Humidity Red Low (uint16)
│  ├─ 0xF007: Humidity Red High (uint16)
│  ├─ 0xF008: PM2.5 Orange Threshold (uint16)
│  └─ 0xF009: PM2.5 Red Threshold (uint16)
└─ Basic, Identify clusters
```

## Sensor Hardware

```
┌─────────────────────────────────────────────────────────────────┐
│                          I2C Bus (GPIO6/7)                       │
│                           100 kHz, 3.3V                          │
└─────────────────────────────────────────────────────────────────┘
    │
    ├─ SHT45 (0x44)      → Temperature & Humidity
    ├─ LPS22HB (0x5D)    → Pressure
    ├─ SGP41 (0x59)      → VOC Raw Signals → VOC Index
    └─ SCD40 (0x62)      → CO2

┌─────────────────────────────────────────────────────────────────┐
│                       UART (GPIO20, 9600)                        │
└─────────────────────────────────────────────────────────────────┘
    │
    └─ PMSA003A          → PM1.0, PM2.5, PM10

┌─────────────────────────────────────────────────────────────────┐
│                     RMT (4 channels, 10MHz)                      │
└─────────────────────────────────────────────────────────────────┘
    │
    ├─ SK6812 RGB LED (GPIO21)  → CO2 Level Indicator
    ├─ SK6812 RGB LED (GPIO4)   → VOC Index Indicator
    ├─ SK6812 RGB LED (GPIO5)   → PM2.5 Level Indicator
    └─ SK6812 RGB LED (GPIO10)  → Humidity Level Indicator
```

## Update Cycle

```
Every 30 seconds:
  ┌────────────────────────────────────────┐
  │ 1. Read all sensors                    │
  │    - SHT45: Temp, Humidity             │
  │    - LPS22HB: Pressure                 │
  │    - PMSA003A: PM1.0, PM2.5, PM10      │
  │    - SGP41: VOC Index                  │
  │    - SCD40: CO2                        │
  └────────────────────────────────────────┘
              ↓
  ┌────────────────────────────────────────┐
  │ 2. Update Zigbee attributes            │
  │    - Endpoints 1-7 sensor values       │
  └────────────────────────────────────────┘
              ↓
  ┌────────────────────────────────────────┐
  │ 3. Evaluate each LED independently     │
  │    - CO2 LED: Check CO2 vs thresholds  │
  │    - VOC LED: Check VOC vs thresholds  │
  │    - Hum LED: Check Hum vs thresholds  │
  │    - PM2.5 LED: Check PM vs thresholds │
  └────────────────────────────────────────┘
              ↓
  ┌────────────────────────────────────────┐
  │ 4. Update each LED color (if changed)  │
  │    - Each LED: Green/Orange/Red/Off    │
  └────────────────────────────────────────┘
```

## LED Color Logic (Per LED)

```
VOC LED:
  ┌─────────────────────────────────────────────────────────┐
  │ IF VOC >= voc_red_threshold           → RED             │
  │ ELSE IF VOC >= voc_orange_threshold   → ORANGE          │
  │ ELSE                                  → GREEN           │
  └─────────────────────────────────────────────────────────┘

CO2 LED:
  ┌─────────────────────────────────────────────────────────┐
  │ IF CO2 >= co2_red_threshold           → RED             │
  │ ELSE IF CO2 >= co2_orange_threshold   → ORANGE          │
  │ ELSE                                  → GREEN           │
  └─────────────────────────────────────────────────────────┘

Humidity LED (special case - range check):
  ┌─────────────────────────────────────────────────────────┐
  │ IF humidity <= hum_red_low OR >= hum_red_high → RED     │
  │ ELSE IF humidity <= hum_orange_low OR >= hum_orange_high│
  │                                           → ORANGE       │
  │ ELSE                                      → GREEN        │
  └─────────────────────────────────────────────────────────┘

PM2.5 LED:
  ┌─────────────────────────────────────────────────────────┐
  │ IF PM2.5 >= pm25_red_threshold        → RED             │
  │ ELSE IF PM2.5 >= pm25_orange_threshold → ORANGE         │
  │ ELSE                                  → GREEN           │
  └─────────────────────────────────────────────────────────┘

Global enable/disable:
  ┌─────────────────────────────────────────────────────────┐
  │ IF LED disabled via Zigbee     → ALL LEDs = OFF         │
  └─────────────────────────────────────────────────────────┘
```

## Zigbee2MQTT Device Structure

```json
{
  "ieee_address": "0x...",
  "friendly_name": "Aeris Air Quality Sensor",
  "model": "aeris-z",
  "vendor": "ESPRESSIF",
  "definition": {
    "endpoints": {
      "1": ["temperature", "humidity"],
      "2": ["pressure"],
      "3": ["pm1_0"],
      "4": ["pm2_5"],
      "5": ["pm10"],
      "6": ["voc_index"],
      "7": ["co2"],
      "8": ["led_config", "thresholds"]
    }
  }
}
```

## Pin Assignment Summary

| GPIO | Function | Device | Protocol |
|---|---|---|---|
| 3 | Antenna SEL0 | FM8625H | Digital Out |
| 4 | RMT Data | SK6812 VOC LED | RMT |
| 5 | RMT Data | SK6812 PM2.5 LED | RMT |
| 6 | I2C SDA | Sensors | I2C |
| 7 | I2C SCL | Sensors | I2C |
| 9 | Boot Button | Factory Reset | Digital In |
| 10 | RMT Data | SK6812 Humidity LED | RMT |
| 14 | Antenna SEL1 | FM8625H | Digital Out |
| 20 | UART RX | PMSA003A | UART |
| 21 | RMT Data | SK6812 CO2 LED | RMT |

## Power Budget (Estimated)

| Component | Current | Notes |
|---|---|---|
| ESP32-C6 | ~80mA | Active, Zigbee router |
| SHT45 | <0.5mA | Measurement mode |
| LPS22HB | <0.1mA | Low power mode |
| SGP41 | ~3mA | Active measurement |
| SCD40 | ~20mA | Active measurement |
| PMSA003A | ~100mA | Fan + laser active |
| SK6812 LEDs (×4) | ~240mA | Max brightness, all colors, all LEDs |
| **Total** | **~445mA** | Peak during measurement |

USB 5V supply required (min 1A recommended for margin).

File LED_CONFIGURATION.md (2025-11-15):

# RGB LED Air Quality Indicators

## Overview
The Aeris_zb air quality sensor includes **4 separate RGB LEDs (SK6812)** that provide independent visual feedback for each air quality parameter:

- **CO2 LED** - Carbon dioxide level indicator
- **VOC LED** - Volatile organic compounds indicator  
- **PM2.5 LED** - Particulate matter indicator
- **Humidity LED** - Humidity level indicator

Each LED shows:
- **Green** - Parameter is in good range
- **Orange** - Parameter is not ideal (warning level)
- **Red** - Parameter is poor (danger level)

All 4 LEDs can be enabled/disabled together with a single Zigbee On/Off command.

## Hardware Connection
Connect 4 SK6812 RGB LEDs to the Xiao ESP32-C6:

| LED Purpose | GPIO | Connection |
|---|---|---|
| CO2 | GPIO21 | Data line |
| VOC | GPIO4 | Data line |
| PM2.5 | GPIO5 | Data line |
| Humidity | GPIO10 | Data line |

For each LED:
- Data → GPIO pin (see table above)
- VCC → 3.3V or 5V (depending on LED spec)
- GND → GND

You can change the GPIO pins in `main/board.h` if needed.

## Zigbee Configuration
The LED is controlled via **Endpoint 8** with the following clusters:

### On/Off Cluster (0x0006)
- **Attribute 0x0000 (OnOff)**: Enable/disable ALL 4 LEDs simultaneously
  - `true` = All LEDs enabled (show air quality status)
  - `false` = All LEDs disabled (always off)

### Analog Output Cluster (0x000D) - Threshold Attributes
Custom manufacturer-specific attributes for configuring thresholds:

| Attribute ID | Parameter | Default | Description |
|---|---|---|---|
| 0xF000 | VOC Orange | 150 | VOC Index warning level (1-500 scale) |
| 0xF001 | VOC Red | 250 | VOC Index danger level |
| 0xF002 | CO2 Orange | 1000 | CO2 warning level (ppm) |
| 0xF003 | CO2 Red | 1500 | CO2 danger level (ppm) |
| 0xF004 | Humidity Orange Low | 30 | Too dry warning (%) |
| 0xF005 | Humidity Orange High | 70 | Too humid warning (%) |
| 0xF006 | Humidity Red Low | 20 | Too dry danger (%) |
| 0xF007 | Humidity Red High | 80 | Too humid danger (%) |
| 0xF008 | PM2.5 Orange | 25 | PM2.5 warning level (µg/m³) |
| 0xF009 | PM2.5 Red | 55 | PM2.5 danger level (µg/m³) |

## Zigbee2MQTT Configuration

### Example Configuration
Add this to your Zigbee2MQTT device configuration or external converter:

```javascript
const fz = require('zigbee-herdsman-converters/converters/fromZigbee');
const tz = require('zigbee-herdsman-converters/converters/toZigbee');
const exposes = require('zigbee-herdsman-converters/lib/exposes');
const reporting = require('zigbee-herdsman-converters/lib/reporting');
const e = exposes.presets;
const ea = exposes.access;

const definition = {
    zigbeeModel: ['aeris-z'],
    model: 'aeris-z',
    vendor: 'ESPRESSIF',
    description: 'Air Quality Sensor with RGB LED',
    
    fromZigbee: [fz.on_off, fz.analog_input],
    toZigbee: [tz.on_off],
    
    exposes: [
        // Endpoint 1: Temperature & Humidity
        e.temperature().withEndpoint('temp_hum'),
        e.humidity().withEndpoint('temp_hum'),
        
        // Endpoint 2: Pressure
        e.pressure().withEndpoint('pressure'),
        
        // Endpoint 3-5: PM sensors
        e.numeric('pm1_0', ea.STATE).withUnit('µg/m³').withDescription('PM1.0').withEndpoint('pm1'),
        e.numeric('pm2_5', ea.STATE).withUnit('µg/m³').withDescription('PM2.5').withEndpoint('pm25'),
        e.numeric('pm10', ea.STATE).withUnit('µg/m³').withDescription('PM10').withEndpoint('pm10'),
        
        // Endpoint 6: VOC
        e.numeric('voc_index', ea.STATE).withDescription('VOC Index (1-500)').withEndpoint('voc'),
        
        // Endpoint 7: CO2
        e.co2().withEndpoint('co2'),
        
        // Endpoint 8: LED Configuration
        e.binary('led_enabled', ea.ALL, true, false)
            .withDescription('Enable/disable air quality LED indicator')
            .withEndpoint('led_config'),
        
        // LED Thresholds
        e.numeric('voc_orange_threshold', ea.ALL).withValueMin(0).withValueMax(500)
            .withDescription('VOC Index orange (warning) threshold').withEndpoint('led_config'),
        e.numeric('voc_red_threshold', ea.ALL).withValueMin(0).withValueMax(500)
            .withDescription('VOC Index red (danger) threshold').withEndpoint('led_config'),
        
        e.numeric('co2_orange_threshold', ea.ALL).withValueMin(400).withValueMax(5000).withUnit('ppm')
            .withDescription('CO2 orange (warning) threshold').withEndpoint('led_config'),
        e.numeric('co2_red_threshold', ea.ALL).withValueMin(400).withValueMax(5000).withUnit('ppm')
            .withDescription('CO2 red (danger) threshold').withEndpoint('led_config'),
        
        e.numeric('humidity_orange_low', ea.ALL).withValueMin(0).withValueMax(100).withUnit('%')
            .withDescription('Humidity too dry - orange threshold').withEndpoint('led_config'),
        e.numeric('humidity_orange_high', ea.ALL).withValueMin(0).withValueMax(100).withUnit('%')
            .withDescription('Humidity too humid - orange threshold').withEndpoint('led_config'),
        
        e.numeric('humidity_red_low', ea.ALL).withValueMin(0).withValueMax(100).withUnit('%')
            .withDescription('Humidity too dry - red threshold').withEndpoint('led_config'),
        e.numeric('humidity_red_high', ea.ALL).withValueMin(0).withValueMax(100).withUnit('%')
            .withDescription('Humidity too humid - red threshold').withEndpoint('led_config'),
        
        e.numeric('pm25_orange_threshold', ea.ALL).withValueMin(0).withValueMax(500).withUnit('µg/m³')
            .withDescription('PM2.5 orange (warning) threshold').withEndpoint('led_config'),
        e.numeric('pm25_red_threshold', ea.ALL).withValueMin(0).withValueMax(500).withUnit('µg/m³')
            .withDescription('PM2.5 red (danger) threshold').withEndpoint('led_config'),
    ],
    
    endpoint: (device) => {
        return {
            'temp_hum': 1,
            'pressure': 2,
            'pm1': 3,
            'pm25': 4,
            'pm10': 5,
            'voc': 6,
            'co2': 7,
            'led_config': 8,
        };
    },
    
    meta: {
        multiEndpoint: true,
    },
};

module.exports = definition;
```

### Setting Thresholds via MQTT

To configure LED thresholds via MQTT, publish to:
```
zigbee2mqtt/[DEVICE_NAME]/set
```

Examples:
```json
# Enable LED
{"led_enabled": true}

# Disable LED
{"led_enabled": false}

# Set VOC thresholds
{"voc_orange_threshold": 150, "voc_red_threshold": 250}

# Set CO2 thresholds (ppm)
{"co2_orange_threshold": 1000, "co2_red_threshold": 1500}

# Set humidity thresholds (%)
{"humidity_orange_low": 30, "humidity_orange_high": 70, "humidity_red_low": 20, "humidity_red_high": 80}

# Set PM2.5 thresholds (µg/m³)
{"pm25_orange_threshold": 25, "pm25_red_threshold": 55}
```

## Air Quality Guidelines

### VOC Index (Sensirion SGP41)
- 0-100: Excellent
- 101-150: Good
- **151-250: Not ideal** (Orange)
- **251-500: Poor** (Red)

### CO2 (ppm)
- 400-1000: Normal indoor levels
- **1001-1500: Not ideal** (Orange) - ventilation recommended
- **1501+: Poor** (Red) - increase ventilation

### Humidity (%)
- **<20%: Too dry** (Red) - health concerns
- **20-30%: Dry** (Orange) - not ideal
- 30-70%: Comfortable range
- **70-80%: Humid** (Orange) - may feel uncomfortable
- **>80%: Too humid** (Red) - mold risk

### PM2.5 (µg/m³) - EPA Air Quality Index
- 0-12: Good
- 13-25: Moderate
- **26-55: Unhealthy for sensitive groups** (Orange)
- **56+: Unhealthy** (Red)

## Home Assistant Integration

The LED configuration will appear as separate entities in Home Assistant:
- `switch.aeris_led_enabled` - Enable/disable LED
- `number.aeris_voc_orange_threshold` - VOC warning level
- `number.aeris_voc_red_threshold` - VOC danger level
- etc.

You can create automations or scripts to adjust thresholds based on your preferences.

## Troubleshooting

**LED not lighting up:**
- Check GPIO21 connection
- Verify LED power (3.3V or 5V depending on SK6812 spec)
- Check that LED is enabled via Zigbee (OnOff attribute = true)
- Monitor logs for LED initialization errors

**LED showing wrong color:**
- Verify sensor readings are accurate
- Check threshold configuration
- Remember: worst sensor condition determines color

**Cannot change thresholds:**
- Ensure device is properly paired with Zigbee2MQTT
- Check that endpoint 8 is accessible
- Verify attribute IDs are correctly mapped in Z2M converter

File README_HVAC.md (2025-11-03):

# Zigbee Air Quality Sensor - Aeris

This project implements a Zigbee End Device that reads air quality sensors and exposes them as standard Zigbee sensor endpoints.

## Hardware Requirements

- ESP32-C6 development board (or compatible)
- Air quality sensors:
  - Temperature and Humidity sensor (e.g., SHT4x, BME280) via I2C
  - **LPS22HB Pressure sensor** via I2C
  - **PMSA003A Particulate Matter sensor** via UART
  - **SGP41 VOC and NOx sensor** via I2C
  - CO2 sensor (e.g., SCD40, SCD41) via I2C
- I2C connection (SDA/SCL pins configurable)
- UART connection for PMSA003A (RX pin configurable)

## Features

The Zigbee air quality sensor exposes the following sensor endpoints:

### Endpoint 1: Temperature and Humidity Sensor
- **Temperature Measurement Cluster (0x0402)**: Temperature in °C
- **Relative Humidity Measurement Cluster (0x0405)**: Humidity in %

### Endpoint 2: Pressure Sensor
- **Pressure Measurement Cluster (0x0403)**: Atmospheric pressure in hPa
- **Sensor**: STMicroelectronics LPS22HB (I2C)
- **Update Rate**: 25 Hz (configurable)
- **Range**: 260-1260 hPa
- **Accuracy**: ±0.025 hPa (typical)

### Endpoint 3: Particulate Matter (PM) Sensor
- **PM2.5 Measurement**: Fine particulate matter (µg/m³) from PMSA003A
- **PM10 Measurement**: Coarse particulate matter (µg/m³) from PMSA003A
- **PM1.0 Measurement**: Ultra-fine particulate matter (µg/m³) from PMSA003A
- **Sensor**: Plantower PMSA003A (UART, 9600 baud)
- **Update Rate**: ~1 second (automatic)

### Endpoint 4: VOC Index Sensor
- **VOC Index** (1-500): Volatile Organic Compounds air quality index
- **NOx Index** (1-500): Nitrogen Oxides air quality index
- **Sensor**: Sensirion SGP41 (I2C)
- **Raw signals**: VOC and NOx raw values available
- **Update Rate**: 1 second recommended
- **Note**: Requires temperature/humidity compensation

### Endpoint 5: CO2 Sensor
- **CO2 Concentration Cluster (0x040D)**: Carbon dioxide in ppm

## I2C and UART Configuration

### I2C Bus (Temperature, Humidity, Pressure, VOC, CO2)

The device communicates with most sensors via I2C:

- **SDA Pin**: GPIO 6 (configurable in `aeris_driver.h`)
- **SCL Pin**: GPIO 7 (configurable in `aeris_driver.h`)
- **Frequency**: 100 kHz
- **Pull-ups**: Internal pull-ups enabled

**I2C Addresses:**
- LPS22HB (Pressure): 0x5C (default, SA0=0) or 0x5D (SA0=1)
- SGP41 (VOC/NOx): 0x59 (fixed address)

### UART for PMSA003A (Particulate Matter Sensor)

The PMSA003A sensor uses UART communication:

- **RX Pin**: GPIO 20 (receives data from PMSA003A TX)
- **TX Pin**: GPIO 18 (not used - PMSA003A is read-only)
- **Baud Rate**: 9600
- **Data Format**: 8N1 (8 data bits, no parity, 1 stop bit)
- **Frame Length**: 32 bytes
- **Update Rate**: ~1 second (automatic from sensor)

**PMSA003A Data Format:**
- Start characters: 0x42 0x4D
- Frame length: 28 data bytes + 2 byte checksum
- PM1.0, PM2.5, PM10 concentrations (both CF=1 and atmospheric)
- Particle counts for various size ranges

## Project Structure

```
Aeris_zb/
├── main/
│   ├── esp_zb_aeris.c         # Main Zigbee application
│   ├── esp_zb_aeris.h         # Zigbee configuration header
│   ├── aeris_driver.c         # Air quality sensor driver implementation
│   ├── aeris_driver.h         # Sensor driver header
│   ├── esp_zb_ota.c           # OTA update support
│   ├── esp_zb_ota.h           # OTA header
│   ├── board.h                # Board pin definitions
│   ├── CMakeLists.txt         # Component build configuration
│   └── idf_component.yml      # Component dependencies
├── CMakeLists.txt             # Project CMakeLists
├── sdkconfig                  # ESP-IDF configuration
└── README.md                  # This file
```

## Building and Flashing

1. Set up ESP-IDF v5.5.1 or later
2. Configure the project:
   ```bash
   idf.py set-target esp32c6
   idf.py menuconfig
   ```
3. Build the project:
   ```bash
   idf.py build
   ```
4. Flash to device:
   ```bash
   idf.py -p COMx flash monitor
   ```

## Configuration

### Zigbee Configuration

The device is configured as a Zigbee End Device (ZED):
- **Endpoints**: 1-5 (one per sensor type)
- **Profile**: Home Automation (0x0104)
- **Device IDs**: Various sensor types (Temperature, Humidity, Pressure, etc.)
- **Channel Mask**: All channels

### Sensor Configuration

Configure sensor I2C addresses and settings in `aeris_driver.c`:
- Default I2C pins: SDA=GPIO6, SCL=GPIO7
- Adjust pins in `aeris_driver.h` if needed

### Joining the Network

On first boot, the device will automatically enter network steering mode. Once joined, the device will save the network credentials and automatically rejoin on subsequent boots.

## Usage

### From Zigbee Coordinator (e.g., Zigbee2MQTT, Home Assistant)

1. Put your coordinator in pairing mode
2. Power on the ESP32-C6 device
3. Wait for the device to join (check logs)
4. The air quality sensor will appear with the following entities:
   - Temperature (°C)
   - Humidity (%)
   - Pressure (hPa)
   - PM1.0, PM2.5, PM10 (µg/m³)
   - VOC Index (1-500)
   - CO2 (ppm)

### Sensor Reading Updates

- Sensors are polled periodically (configurable interval)
- Values are reported to the Zigbee coordinator when they change
- All endpoints support binding and reporting configuration

## Supported Sensors

This project provides a framework for air quality sensors. You'll need to implement the actual sensor drivers:

### Temperature/Humidity
- **SHT4x** (recommended): High accuracy, low power
- **BME280**: Temperature, humidity, and pressure in one chip
- **DHT22**: Budget option

### Pressure
- **LPS22HB** (implemented): STMicroelectronics MEMS pressure sensor
  - I2C interface (address 0x5C or 0x5D)
  - Measures 260-1260 hPa
  - ±0.025 hPa accuracy
  - Internal temperature sensor (bonus)
  - Low power: 3 µA @ 1Hz
  - Configurable output rate (1-75 Hz)
- **Alternative**: BMP280, BME280 (Bosch sensors)

### Particulate Matter
- **PMSA003A** (implemented): Plantower laser PM sensor
  - UART interface (9600 baud)
  - Measures PM1.0, PM2.5, PM10
  - Automatic 1-second updates
  - Low power consumption
  - Atmospheric environment correction included
- **Alternative**: PMS5003 (similar protocol, same manufacturer)

### VOC Index
- **SGP41** (implemented): Sensirion VOC and NOx sensor
  - I2C interface (address 0x59)
  - Dual gas sensing: VOC + NOx
  - Raw signal output (requires algorithm)
  - Temperature/humidity compensation
  - Built-in heater for measurement
  - Low power: 2.6 mA average @ 1Hz
  - Serial number readout
  - Self-test capability
- **Note**: Full Gas Index Algorithm integration recommended for production
- **Alternative**: SGP40 (VOC only), BME680 (combo sensor)

### CO2
- **SCD40**: NDIR CO2 sensor (400-2000 ppm)
- **SCD41**: Extended range (400-5000 ppm)

## Implementation Notes

The `aeris_driver.c` file contains:

1. **PMSA003A implementation** (complete):
   - UART initialization and configuration
   - Background task for continuous reading
   - Frame parsing with checksum validation
   - Automatic atmospheric environment values
   - Particle count data available

2. **LPS22HB implementation** (complete):
   - I2C initialization and device detection
   - WHO_AM_I verification (0xB1)
   - 25 Hz output data rate
   - Block data update enabled
   - Pressure reading in hPa
   - Temperature reading included

3. **SGP41 implementation** (complete):
   - I2C initialization and device detection
   - Serial number readout and verification
   - Self-test execution
   - Raw VOC and NOx signal measurement
   - Temperature/humidity compensation support
   - CRC8 validation on all data
   - Placeholder index calculation (needs Gas Index Algorithm)

4. **I2C sensor stubs** (need implementation):
   - Temperature/Humidity sensor
   - CO2 sensor

### PMSA003A Wiring

```
PMSA003A Pin → ESP32-C6
VCC (Pin 1)  → 5V
GND (Pin 2)  → GND
SET (Pin 3)  → Not connected (or 5V for continuous mode)
RX  (Pin 4)  → Not connected
TX  (Pin 5)  → GPIO 20 (ESP32 UART RX)
RESET (Pin 6)→ Not connected (or 5V)
NC  (Pin 7)  → Not connected
NC  (Pin 8)  → Not connected
```

**Note**: PMSA003A requires 5V power supply. TX output is 3.3V compatible.

### LPS22HB Wiring

```
LPS22HB Pin → ESP32-C6
VDD         → 3.3V
GND         → GND
SCL         → GPIO 7 (I2C SCL)
SDA         → GPIO 6 (I2C SDA)
SA0         → GND (for address 0x5C) or 3.3V (for 0x5D)
```

**Note**: LPS22HB operates at 1.7-3.6V. Use 3.3V supply.

### SGP41 Wiring

```
SGP41 Pin → ESP32-C6
VDD       → 3.3V
GND       → GND
SCL       → GPIO 7 (I2C SCL)
SDA       → GPIO 6 (I2C SDA)
```

**Note**: SGP41 operates at 1.7-3.6V. Use 3.3V supply. No external pull-ups needed on most breakout boards.

### Important: Gas Index Algorithm

The SGP41 currently uses a **simplified placeholder** for VOC/NOx index calculation. For production use, integrate Sensirion's **Gas Index Algorithm**:

- Download from: https://github.com/Sensirion/gas-index-algorithm
- Provides proper VOC Index (1-500) and NOx Index (1-500)
- Requires learning period (~10 minutes for VOC, ~12 hours for NOx)
- Handles baseline tracking and auto-calibration

## Removed Features

This project was adapted from an HVAC controller. The following features were removed:

- ❌ HVAC thermostat control
- ❌ Fan speed control
- ❌ Eco/Night/Swing modes
- ❌ UART communication with HVAC unit

All HVAC control logic has been replaced with air quality sensor reading functionality.

## Troubleshooting

### Device won't join network
- Check that Zigbee coordinator is in pairing mode
- Verify ESP32-C6 is powered correctly
- Check serial logs for error messages
- Try factory reset (hold button during boot)

### Sensors not responding
- **I2C sensors**:
  - Verify I2C wiring (SDA/SCL connections)
  - Check I2C pull-up resistors (usually 4.7kΩ)
  - Verify sensor power supply (3.3V for LPS22HB)
  - Use `i2cdetect` to scan for sensor addresses
  - Monitor I2C traffic in logs
  - **LPS22HB**: Check WHO_AM_I register (should be 0xB1)
  - **LPS22HB**: Verify address 0x5C or 0x5D (depends on SA0 pin)
  - **SGP41**: Check serial number readout
  - **SGP41**: Verify self-test passes (result 0xD400)
  - **SGP41**: Ensure temperature/humidity data is available for compensation
- **PMSA003A (PM sensor)**:
  - Verify UART RX connection (PMSA003A TX → GPIO20)
  - Check 5V power supply to sensor
  - Ensure baud rate is 9600
  - Look for "PMSA003A data:" log messages
  - Check frame checksum errors in logs

### Values not updating
- Check that sensors are initialized correctly
- Verify periodic read task is running
- Check log output for sensor read errors
- Ensure reporting is configured on Zigbee coordinator

### Build errors
- Make sure ESP-IDF v5.5.1+ is installed
- Run `idf.py fullclean` and rebuild
- Check that all sensor libraries are in `idf_component.yml`

## License

This code is based on Espressif's Zigbee examples and inherits their licensing.

## Credits

- Base Zigbee framework: Espressif ESP-IDF examples
- Air quality sensor concept: Community contributions
- Original ESPHome component: See `CodeToReusePartially/acw02_esphome/`

## Future Enhancements

- [ ] Add button for factory reset
- [ ] Implement command retry logic
- [ ] Add OTA firmware update support
- [ ] Support horizontal swing control
- [ ] Add night mode support
- [ ] Implement filter status monitoring
- [ ] Add clean mode support

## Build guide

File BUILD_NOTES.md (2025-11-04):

# Aeris Air Quality Sensor - Build Notes

## Summary of Changes

The Zigbee endpoint creation code in `esp_zb_aeris.c` has been updated to use the correct ESP-IDF Zigbee API patterns based on the working example code in `doc/esp_zb_light.c`.

### Key Changes Made

1. **Fixed endpoint registration** - Changed from incorrect API usage to proper `esp_zb_ep_list_add_ep()` calls with `esp_zb_endpoint_config_t` struct parameter

2. **Implemented all 5 sensor endpoints:**
   - **Endpoint 1 (Temperature & Humidity)**: Uses Temperature Measurement and Humidity Measurement clusters
   - **Endpoint 2 (Pressure)**: Uses Pressure Measurement cluster  
   - **Endpoint 3 (PM2.5)**: Uses Analog Input cluster with description "PM2.5 µg/m³"
   - **Endpoint 4 (VOC Index)**: Uses Analog Input cluster with description "VOC Index"
   - **Endpoint 5 (CO2)**: Uses Carbon Dioxide Measurement cluster

3. **Added Basic and Identify clusters** to all endpoints (required for proper Zigbee Home Automation profile compliance)

4. **Implemented attribute updates** in `sensor_update_zigbee_attributes()`:
   - Temperature: Converted to centidegrees (°C × 100)
   - Humidity: Converted to centipercent (% × 100)
   - Pressure: Converted to 0.1 hPa units (hPa × 10)
   - PM2.5: Direct float value in µg/m³
   - VOC Index: Integer converted to float
   - CO2: Integer ppm value converted to float

5. **Proper cluster initialization** with correct initial values:
   - Temperature: 0x8000 (invalid/unknown)
   - Humidity: 0xFFFF (invalid/unknown)
   - Pressure: `ESP_ZB_ZCL_ATTR_PRESSURE_MEASUREMENT_VALUE_UNKNOWN`
   - All others: 0.0 or appropriate defaults

## IntelliSense Errors (Can Be Ignored)

VS Code IntelliSense is showing errors about missing header files. These are **configuration issues**, not real compilation errors:

```
cannot open source file "freertos/FreeRTOS.h"
cannot open source file "esp_log.h"
#include errors detected. Please update your includePath.
```

**These errors do not affect the actual ESP-IDF build process.** They appear because VS Code doesn't have the ESP-IDF environment configured for IntelliSense.

### Why These Can Be Ignored

1. ESP-IDF uses its own build system (CMake + Ninja)
2. The actual compilation uses the ESP-IDF toolchain which has all headers
3. IntelliSense uses a different path resolution system
4. The project builds successfully with `idf.py build` despite IntelliSense errors

## Building the Project

### Prerequisites

1. **ESP-IDF v5.5.1 or later** must be installed
2. ESP-IDF environment must be activated in your terminal

### Build Steps

#### Windows PowerShell:

```powershell
# Navigate to project directory
cd C:\Devel\Repositories\Aeris_zb

# Activate ESP-IDF environment (adjust path to your ESP-IDF installation)
. $HOME\esp\esp-idf\export.ps1

# Set target (if not already set)
idf.py set-target esp32c6

# Build the project
idf.py build

# Flash to device (with COM port, e.g., COM3)
idf.py -p COM3 flash monitor
```

#### Windows Command Prompt:

```cmd
cd C:\Devel\Repositories\Aeris_zb
%USERPROFILE%\esp\esp-idf\export.bat
idf.py set-target esp32c6
idf.py build
idf.py -p COM3 flash monitor
```

### Expected Build Output

If the build succeeds, you should see:
```
Project build complete. To flash, run:
 idf.py flash
or
 python -m esptool ...
```

## Code Structure

### Sensor Drivers (`aeris_driver.c`)
- ✅ All 5 sensors implemented (SHT45, LPS22HB, PMSA003A, SGP41, SCD40)
- ✅ I2C and UART protocols
- ✅ CRC-8 validation
- ✅ SCD40 pressure compensation using LPS22HB data

### Zigbee Application (`esp_zb_aeris.c`)
- ✅ 5 endpoints correctly registered
- ✅ Attribute updates implemented
- ✅ Periodic sensor reading (5-second initial delay, then SENSOR_UPDATE_INTERVAL_MS)
- ✅ Signal handlers for JOIN/LEAVE events
- ✅ Factory reset on 5-second button hold

### Configuration (`esp_zb_aeris.h`)
- ✅ Endpoint IDs defined (1-5)
- ✅ Device type: ZED (End Device) - **Note:** To use as Router, change to ESP_ZB_DEVICE_TYPE_ROUTER
- ✅ Home Automation profile (0x0104)
- ✅ All channels enabled

## Next Steps

1. **Build the project** using the commands above
2. **Flash to ESP32-C6** hardware
3. **Monitor output** to verify sensor initialization
4. **Join Zigbee network** (device will start network steering automatically)
5. **Verify sensor data** is being read and reported

## Troubleshooting

### If build fails:

1. Verify ESP-IDF is installed: `idf.py --version`
2. Check target is set: `idf.py get-target` (should show `esp32c6`)
3. Clean build: `idf.py fullclean` then `idf.py build`
4. Check managed components: `idf.py reconfigure`

### If sensors don't initialize:

1. Check I2C wiring (SDA=GPIO6, SCL=GPIO7)
2. Check UART wiring for PMSA003A (RX=GPIO20)
3. Verify sensor I2C addresses match configuration
4. Check serial monitor for initialization error messages

### If device doesn't join network:

1. Verify Zigbee coordinator is running and in pairing mode
2. Check channel mask matches coordinator
3. Factory reset device (hold button 5 seconds)
4. Check logs for error messages during network steering

## Reference

The endpoint creation pattern was taken from the working example in `doc/esp_zb_light.c`, which demonstrates proper usage of:
- `esp_zb_zcl_cluster_list_create()`
- `esp_zb_XXX_cluster_create()` functions
- `esp_zb_cluster_list_add_XXX_cluster()` functions
- `esp_zb_endpoint_config_t` struct
- `esp_zb_ep_list_add_ep()` with 3 parameters

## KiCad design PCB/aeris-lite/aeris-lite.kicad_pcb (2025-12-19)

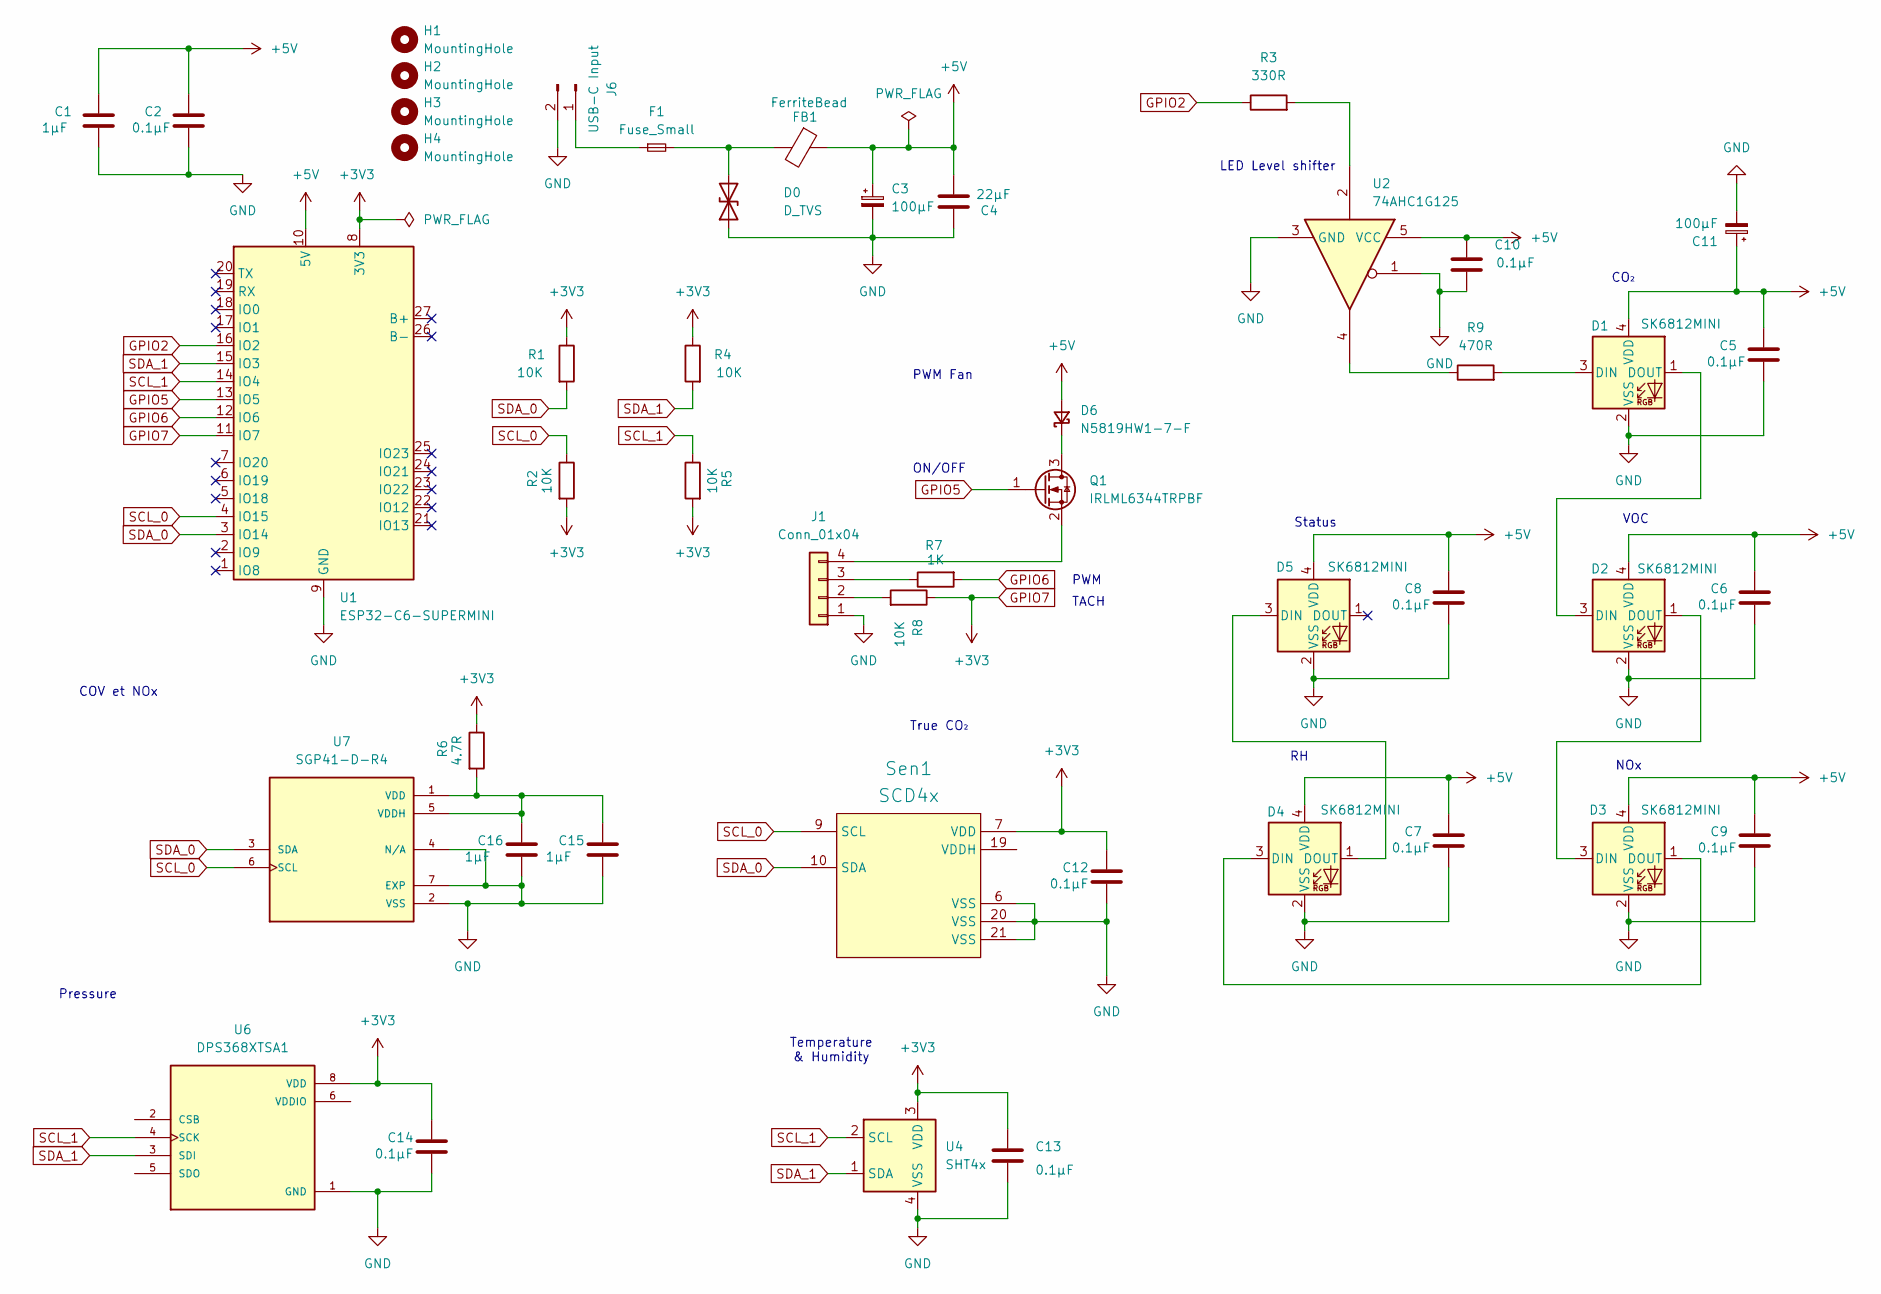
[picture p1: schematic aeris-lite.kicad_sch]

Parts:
C1, C15, C16: 1µF; C_0805_2012Metric
C2, C5, C6, C7, C8, C9, C10, C12, C13, C14: 0.1µF; C_0805_2012Metric
C3, C11: 100µF; CP_Elec_6.3x5.9
C4: 22µF; C_0805_2012Metric
D0: D_TVS; D_SMB
D1, D2, D3, D4, D5: SK6812MINI; LED_SK6812MINI_PLCC4_3.5x3.5mm_P1.75mm
D6: N5819HW1-7-F; D_SOD-123F
F1: Fuse_Small; Fuse_1206_3216Metric
FB1: FerriteBead; L_1206_3216Metric
H1, H2, H3, H4: MountingHole; MountingHole_2.2mm_M2
J1: Conn_01x04; JST_GH_SM04B-GHS-TB_1x04-1MP_P1.25mm_Horizontal
J6: USB-C Input; PinHeader_1x02_P2.54mm_Vertical
Q1: IRLML6344TRPBF; SOT-23
R1, R2, R4, R5, R8: 10K; R_0805_2012Metric
R3: 330R; R_0805_2012Metric
R6: 4.7R; R_0805_2012Metric
R7: 1K; R_0805_2012Metric
R9: 470R; R_0805_2012Metric
Sen1: SCD4x; Sensirion_SCD4x-1EP_10.1x10.1mm_P1.25mm_EP4.8x4.8mm
U1: ESP32-C6-SUPERMINI; ESP32C6-Supermini
U2: 74AHC1G125; SOT-23-5
U4: SHT4x; Sensirion_DFN-4_1.5x1.5mm_P0.8mm_SHT4x_NoCentralPad
U6: DPS368XTSA1; XDCR_DPS368XTSA1
U7: SGP41-D-R4; XDCR_SGP41-D-R4; PARTREV 1.0

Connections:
+5V: C1.1, C2.1, C3.1, C4.2, C5.1, C6.1, C7.1, C8.1, C9.1, C10.1, C11.1, D1.4 (VDD), D2.4 (VDD), D3.4 (VDD), D4.4 (VDD), D5.4 (VDD), D6.2 (A), FB1.1, U1.10 (5V), U2.5 (VCC)
GND: C1.2, C2.2, C3.2, C4.1, C5.2, C6.2, C7.2, C8.2, C9.2, C10.2, C11.2, C12.2, C13.2, C14.2, C15.2, C16.2, D0.1 (A1), D1.2 (VSS), D2.2 (VSS), D3.2 (VSS), D4.2 (VSS), D5.2 (VSS), J1.1, J6.2, Sen1.6 (VSS), Sen1.20 (VSS), Sen1.21 (VSS), U1.9 (GND), U2.1, U2.3 (GND), U4.4 (VSS), U6.1 (GND), U6.7 (GND), U7.2 (VSS), U7.4 (N/A), U7.7 (EXP)
GPIO2: R3.1, U1.16 (IO2)
GPIO5: Q1.1 (G), U1.13 (IO5)
GPIO6: R7.2, U1.12 (IO6)
GPIO7: C12.1, C13.1, C14.1, R1.1, R2.2, R4.1, R5.2, R6.1, R8.1, Sen1.7 (VDD), U1.8 (3V3), U1.11 (IO7), U4.3 (VDD), U6.8 (VDD)
unnamed: D0.2 (A2), F1.2, FB1.2
unnamed: D1.3 (DIN), R9.2
unnamed: D1.1 (DOUT), D2.3 (DIN)
unnamed: D2.1 (DOUT), D3.3 (DIN)
unnamed: D3.1 (DOUT), D4.3 (DIN)
unnamed: D4.1 (DOUT), D5.3 (DIN)
unnamed: D6.1 (K), Q1.3 (D)
unnamed: J1.2, R8.2
unnamed: J1.3, R7.1
unnamed: J1.4, Q1.2 (S)
unnamed: F1.1, J6.1
unnamed: R3.2, U2.2
unnamed: R9.1, U2.4
unnamed: C15.1, C16.1, R6.2, U7.1 (VDD), U7.5 (VDDH)
SCL_0: R2.1, Sen1.9 (SCL), U1.4 (IO15), U7.6 (SCL)
SCL_1: R5.1, U1.14 (IO4), U4.2 (SCL), U6.4 (SCK)
SDA_0: R1.2, Sen1.10 (SDA), U1.3 (IO14), U7.3 (SDA)
SDA_1: R4.2, U1.15 (IO3), U4.1 (SDA), U6.3 (SDI)

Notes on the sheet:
TACH
VOC
Pressure
ON/OFF
True CO₂
Temperature & Humidity
LED Level shifter
CO₂
Status
PWM
PWM Fan
NOx
COV et NOx

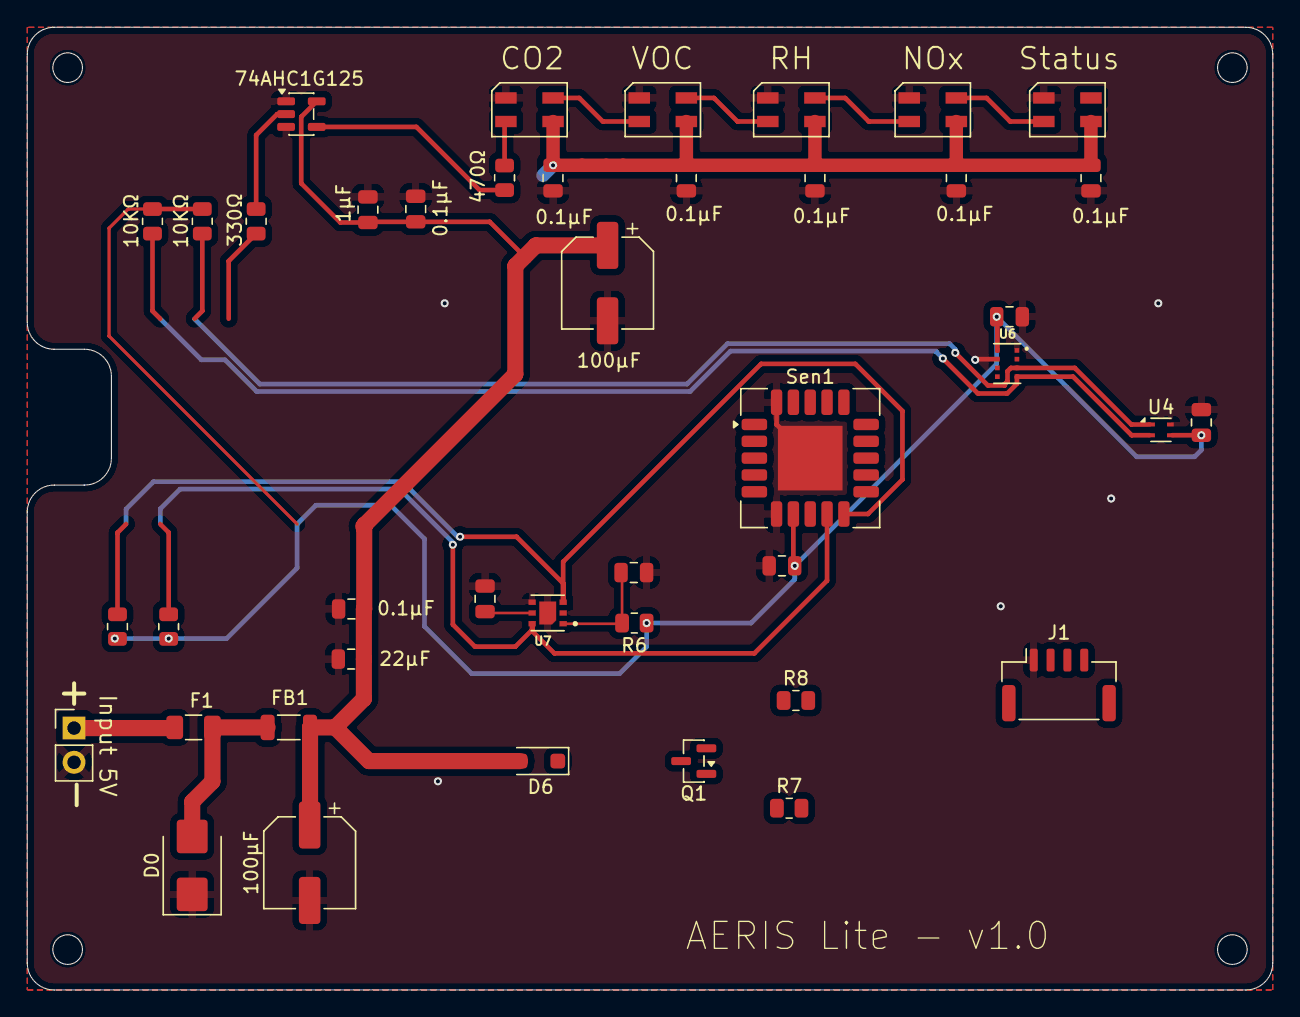
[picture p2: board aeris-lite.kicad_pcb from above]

Board: 2 copper layers, 92.5 x 71.5 mm, 46 parts (0 on the bottom side), 21 nets.

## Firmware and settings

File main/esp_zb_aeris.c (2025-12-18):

/*
 * Zigbee Aeris Air Quality Sensor
 *
 * This code reads air quality sensors and exposes them as Zigbee sensor endpoints
 */
#include "freertos/FreeRTOS.h"
#include "freertos/task.h"
#include "freertos/queue.h"
#include "esp_check.h"
#include "esp_log.h"
#include "nvs_flash.h"
#include "driver/gpio.h"
#include "esp_intr_alloc.h"
#include "board.h"
#include "ha/esp_zigbee_ha_standard.h"
#include "esp_zb_aeris.h"
#include "aeris_driver.h"
#include "esp_zb_ota.h"
#include "esp_zigbee_trace.h"
#include "sdkconfig.h"
#include "esp_ota_ops.h"
#include "esp_system.h"
#include "esp_event.h"
#include "freertos/timers.h"
#include "led_indicator.h"
#include "settings.h"

#if !defined ZB_ROUTER_ROLE
#error Define ZB_ROUTER_ROLE in idf.py menuconfig to compile Router source code.
#endif

static const char *TAG = "AERIS_ZIGBEE";

/* Sensor update interval */
#define SENSOR_UPDATE_INTERVAL_MS   30000  // 30 seconds

/* Boot button configuration for factory reset */
#define BOOT_BUTTON_GPIO            GPIO_NUM_9
#define BUTTON_LONG_PRESS_TIME_MS   5000

/* Status LED blink state */
static TimerHandle_t status_led_blink_timer = NULL;
static bool status_led_blink_state = false;

/********************* Function Declarations **************************/
static esp_err_t deferred_driver_init(void);
static void sensor_update_zigbee_attributes(uint8_t param);
static void sensor_periodic_update(uint8_t param);
static esp_err_t button_init(void);
static void button_task(void *arg);
static void factory_reset_device(uint8_t param);
static void status_led_blink_callback(TimerHandle_t xTimer);

/* OTA validation functions */
void ota_validation_start(void);
void ota_validation_hw_init_ok(void);
void ota_validation_zigbee_init_ok(void);
void ota_validation_zigbee_connected(void);
void ota_validation_mark_invalid(void);

/* Factory reset function */
static void factory_reset_device(uint8_t param)
{
    ESP_LOGW(TAG, "[RESET] Performing factory reset...");
    esp_zb_factory_reset();
    ESP_LOGI(TAG, "[RESET] Factory reset successful - device will restart");
    vTaskDelay(pdMS_TO_TICKS(1000));
    esp_restart();
}

/* Status LED blink timer callback for join animation */
static void status_led_blink_callback(TimerHandle_t xTimer)
{
    // Toggle between green and orange during joining
    status_led_blink_state = !status_led_blink_state;
    led_set_status(status_led_blink_state ? LED_COLOR_GREEN : LED_COLOR_ORANGE);
}

/* Start status LED blinking (green/orange during join) */
static void status_led_start_blink(void)
{
    if (status_led_blink_timer == NULL) {
        status_led_blink_timer = xTimerCreate(
            "status_blink",
            pdMS_TO_TICKS(500),  // 500ms interval
            pdTRUE,              // Auto-reload
            NULL,
            status_led_blink_callback
        );
        
        if (status_led_blink_timer == NULL) {
            ESP_LOGE(TAG, "[ERROR] Failed to create status LED blink timer");
            return;
        }
    }
    
    status_led_blink_state = false;
    led_set_status(LED_COLOR_ORANGE);
    if (xTimerStart(status_led_blink_timer, 0) == pdPASS) {
        ESP_LOGI(TAG, "[STATUS_LED] Started join blink animation");
    } else {
        ESP_LOGE(TAG, "[ERROR] Failed to start status LED timer");
    }
}

/* Stop status LED blinking */
static void status_led_stop_blink(void)
{
    if (status_led_blink_timer != NULL) {
        if (xTimerStop(status_led_blink_timer, 0) == pdPASS) {
            ESP_LOGI(TAG, "[STATUS_LED] Stopped blink animation");
        }
    }
}

/* Boot button queue and ISR handler */
static QueueHandle_t button_evt_queue = NULL;

static void IRAM_ATTR button_isr_handler(void *arg)
{
    uint32_t gpio_num = BOOT_BUTTON_GPIO;
    xQueueSendFromISR(button_evt_queue, &gpio_num, NULL);
}

/* Button monitoring task */
static void button_task(void *arg)
{
    uint32_t io_num;
    TickType_t press_start_time = 0;
    bool long_press_triggered = false;
    const TickType_t LONG_PRESS_DURATION = pdMS_TO_TICKS(BUTTON_LONG_PRESS_TIME_MS);
    const TickType_t DEBOUNCE_TIME = pdMS_TO_TICKS(50);  // 50ms debounce
    
    ESP_LOGI(TAG, "[BUTTON] Task started - waiting for button events");
    
    for (;;) {
        if (xQueueReceive(button_evt_queue, &io_num, portMAX_DELAY)) {
            // Debounce
            vTaskDelay(DEBOUNCE_TIME);
            
            gpio_intr_disable(BOOT_BUTTON_GPIO);
            int button_level = gpio_get_level(BOOT_BUTTON_GPIO);
            
            if (button_level == 0) {  // Button pressed
                press_start_time = xTaskGetTickCount();
                long_press_triggered = false;
                ESP_LOGI(TAG, "[BUTTON] Pressed - hold 5 sec for factory reset");
                
                // Poll button state with timeout to prevent infinite loop
                TickType_t poll_count = 0;
                const TickType_t MAX_POLL_TIME = pdMS_TO_TICKS(10000);  // 10s max
                
                while (gpio_get_level(BOOT_BUTTON_GPIO) == 0 && poll_count < MAX_POLL_TIME) {
                    TickType_t current_time = xTaskGetTickCount();
                    if ((current_time - press_start_time) >= LONG_PRESS_DURATION && !long_press_triggered) {
                        long_press_triggered = true;
                        ESP_LOGW(TAG, "[BUTTON] Long press detected! Triggering factory reset...");
                        esp_zb_scheduler_alarm((esp_zb_callback_t)factory_reset_device, 0, 100);
                    }
                    vTaskDelay(pdMS_TO_TICKS(100));
                    poll_count += pdMS_TO_TICKS(100);
                }
                
                if (!long_press_triggered) {
                    uint32_t press_duration = pdTICKS_TO_MS(xTaskGetTickCount() - press_start_time);
                    ESP_LOGI(TAG, "[BUTTON] Released (held for %lu ms)", press_duration);
                }
            }
            
            // Re-enable interrupt after debounce
            vTaskDelay(DEBOUNCE_TIME);
            gpio_intr_enable(BOOT_BUTTON_GPIO);
        }
    }
}

/* Initialize boot button */
static esp_err_t button_init(void)
{
    ESP_LOGI(TAG, "[INIT] Initializing boot button on GPIO%d", BOOT_BUTTON_GPIO);
    
    gpio_config_t io_conf = {
        .intr_type = GPIO_INTR_NEGEDGE,
        .pin_bit_mask = (1ULL << BOOT_BUTTON_GPIO),
        .mode = GPIO_MODE_INPUT,
        .pull_up_en = GPIO_PULLUP_ENABLE,
        .pull_down_en = GPIO_PULLDOWN_DISABLE,
    };
    
    esp_err_t ret = gpio_config(&io_conf);
    if (ret != ESP_OK) {
        ESP_LOGE(TAG, "[ERROR] Failed to configure GPIO: %s", esp_err_to_name(ret));
        return ret;
    }
    
    button_evt_queue = xQueueCreate(10, sizeof(uint32_t));
    if (!button_evt_queue) {
        ESP_LOGE(TAG, "[ERROR] Failed to create event queue");
        return ESP_FAIL;
    }
    
    esp_err_t isr_ret = gpio_install_isr_service(ESP_INTR_FLAG_DEFAULT);
    if (isr_ret != ESP_OK && isr_ret != ESP_ERR_INVALID_STATE) {
        ESP_LOGE(TAG, "[ERROR] Failed to install ISR service: %s", esp_err_to_name(isr_ret));
        return isr_ret;
    }
    
    ret = gpio_isr_handler_add(BOOT_BUTTON_GPIO, button_isr_handler, NULL);
    if (ret != ESP_OK) {
        ESP_LOGE(TAG, "[ERROR] Failed to add ISR handler: %s", esp_err_to_name(ret));
        return ret;
    }
    
    BaseType_t task_ret = xTaskCreate(button_task, "button_task", 2048, NULL, 10, NULL);
    if (task_ret != pdPASS) {
        ESP_LOGE(TAG, "[ERROR] Failed to create button task");
        return ESP_FAIL;
    }
    
    ESP_LOGI(TAG, "[OK] Boot button initialization complete");
    return ESP_OK;
}

static esp_err_t deferred_driver_init(void)
{
    ESP_LOGI(TAG, "[INIT] Starting deferred driver initialization...");
    
    /* Initialize boot button for factory reset */
    esp_err_t button_ret = button_init();
    if (button_ret != ESP_OK) {
        ESP_LOGE(TAG, "[ERROR] Button initialization failed");
        return button_ret;
    }
    vTaskDelay(pdMS_TO_TICKS(10));
    
    /* Initialize RGB LED indicator */
    ESP_LOGI(TAG, "[INIT] Initializing RGB LED indicator...");
    esp_err_t led_ret = led_indicator_init();
    if (led_ret != ESP_OK) {
        ESP_LOGE(TAG, "[ERROR] LED initialization failed: %s", esp_err_to_name(led_ret));
        ESP_LOGW(TAG, "[WARN] Continuing without LED indicator");
    } else {
        ESP_LOGI(TAG, "[OK] LED indicator initialized");
        
        /* Apply saved LED settings */
        led_set_brightness(settings_get_led_brightness());
        led_set_enable(settings_get_sensor_leds_enabled());
        led_set_status_enable(settings_get_status_led_enabled());
        
        /* Apply saved LED mask */
        led_thresholds_t thresholds;
        led_get_thresholds(&thresholds);
        thresholds.led_mask = settings_get_led_mask();
        thresholds.enabled = settings_get_sensor_leds_enabled();
        led_set_thresholds(&thresholds);
    }
    
    /* Initialize air quality sensor driver */
    ESP_LOGI(TAG, "[INIT] Initializing air quality sensors...");
    esp_err_t ret = aeris_driver_init();
    
    if (ret != ESP_OK) {
        ESP_LOGE(TAG, "[ERROR] Failed to initialize sensors: %s", esp_err_to_name(ret));
        ESP_LOGW(TAG, "[WARN] Continuing without sensors - endpoints will still be created");
    } else {
        ESP_LOGI(TAG, "[OK] Air quality sensors initialized successfully");
        
        /* Apply saved calibration offsets */
        aeris_set_temperature_offset(settings_get_temperature_offset() / 10.0f);
        aeris_set_humidity_offset(settings_get_humidity_offset() / 10.0f);
    }
    
    ESP_LOGI(TAG, "[INIT] Deferred initialization complete");
    return ESP_OK;
}

static void bdb_start_top_level_commissioning_cb(uint8_t mode_mask)
{
    ESP_RETURN_ON_FALSE(esp_zb_bdb_start_top_level_commissioning(mode_mask) == ESP_OK, , 
                       TAG, "Failed to start Zigbee commissioning");
}

void esp_zb_app_signal_handler(esp_zb_app_signal_t *signal_struct)
{
    uint32_t *p_sg_p = signal_struct->p_app_signal;
    esp_err_t err_status = signal_struct->esp_err_status;
    esp_zb_app_signal_type_t sig_type = *p_sg_p;
    
    switch (sig_type) {
    case ESP_ZB_ZDO_SIGNAL_SKIP_STARTUP:
        ESP_LOGI(TAG, "[JOIN] Initialize Zigbee stack");
        led_set_status(LED_COLOR_ORANGE);  // Not joined yet
        esp_zb_bdb_start_top_level_commissioning(ESP_ZB_BDB_MODE_INITIALIZATION);
        break;
        
    case ESP_ZB_BDB_SIGNAL_DEVICE_FIRST_START:
        ESP_LOGI(TAG, "[JOIN] Device first start - factory new device");
        if (err_status == ESP_OK) {
            deferred_driver_init();
            /* On first start, LED is enabled by default (from cluster config) */
            led_set_enable(true);
            ESP_LOGI(TAG, "[BOOT] LED threshold enabled (factory default)");
            status_led_start_blink();  // Start blinking during join
            esp_zb_bdb_start_top_level_commissioning(ESP_ZB_BDB_MODE_NETWORK_STEERING);
        } else {
            led_set_status(LED_COLOR_RED);  // Error
        }
        break;
        
    case ESP_ZB_BDB_SIGNAL_DEVICE_REBOOT:
        ESP_LOGI(TAG, "[JOIN] Device reboot - previously joined network");
        if (err_status == ESP_OK) {
            deferred_driver_init();
            
            /* Sync LED settings from Zigbee attributes (persisted in NVS) */
            led_thresholds_t thresholds;
            led_get_thresholds(&thresholds);
            
            /* Read LED master enable (On/Off cluster) */
            esp_zb_zcl_attr_t *led_on_off_attr = esp_zb_zcl_get_attribute(
                HA_ESP_LED_CONFIG_ENDPOINT, 
                ESP_ZB_ZCL_CLUSTER_ID_ON_OFF,
                ESP_ZB_ZCL_CLUSTER_SERVER_ROLE,
                ESP_ZB_ZCL_ATTR_ON_OFF_ON_OFF_ID);
            if (led_on_off_attr && led_on_off_attr->data_p) {
                thresholds.enabled = *(bool *)led_on_off_attr->data_p;
                ESP_LOGI(TAG, "[BOOT] LED master enable from NVS: %s", thresholds.enabled ? "ON" : "OFF");
            }
            
            /* Read LED mask (Analog Output cluster, custom attribute) */
            esp_zb_zcl_attr_t *led_mask_attr = esp_zb_zcl_get_attribute(
                HA_ESP_LED_CONFIG_ENDPOINT, 
                ESP_ZB_ZCL_CLUSTER_ID_ANALOG_OUTPUT,
                ESP_ZB_ZCL_CLUSTER_SERVER_ROLE,
                ZCL_LED_ATTR_ENABLE_MASK);
            if (led_mask_attr && led_mask_attr->data_p) {
                thresholds.led_mask = *(uint8_t *)led_mask_attr->data_p;
                ESP_LOGI(TAG, "[BOOT] LED mask from NVS: 0x%02X (CO2:%d VOC:%d NOx:%d Hum:%d)", 
                         thresholds.led_mask,
                         !!(thresholds.led_mask & (1<<0)), !!(thresholds.led_mask & (1<<1)), 
                         !!(thresholds.led_mask & (1<<2)), !!(thresholds.led_mask & (1<<4)));
            }
            
            led_set_thresholds(&thresholds);
            led_set_enable(thresholds.enabled);
            
            if (esp_zb_bdb_is_factory_new()) {
                status_led_start_blink();  // Start blinking during join
                esp_zb_bdb_start_top_level_commissioning(ESP_ZB_BDB_MODE_NETWORK_STEERING);
            } else {
                led_set_status(LED_COLOR_GREEN);  // Previously joined, should reconnect
                /* Start periodic sensor updates for rejoined device */
                esp_zb_scheduler_alarm((esp_zb_callback_t)sensor_periodic_update, 0, 5000);
                ESP_LOGI(TAG, "[JOIN] Sensor updates started for rejoined device");
            }
        } else {
            led_set_status(LED_COLOR_RED);  // Error
        }
        break;
        
    case ESP_ZB_BDB_SIGNAL_STEERING:
        if (err_status == ESP_OK) {
            esp_zb_ieee_addr_t extended_pan_id;
            esp_zb_get_extended_pan_id(extended_pan_id);
            ESP_LOGI(TAG, "[JOIN] *** SUCCESSFULLY JOINED NETWORK ***");
            ESP_LOGI(TAG, "[JOIN] PAN ID: 0x%04hx, Channel: %d", 
                     esp_zb_get_pan_id(), esp_zb_get_current_channel());
            
            status_led_stop_blink();  // Stop blinking
            led_set_status(LED_COLOR_GREEN);  // Connected!
            ota_validation_zigbee_connected();
            
            /* Start periodic sensor updates */
            esp_zb_scheduler_alarm((esp_zb_callback_t)sensor_periodic_update, 0, 5000);
            ESP_LOGI(TAG, "[JOIN] Setup complete!");
        } else {
            ESP_LOGW(TAG, "[JOIN] Network steering failed, retrying...");
            status_led_stop_blink();  // Stop blinking
            led_set_status(LED_COLOR_RED);  // Join failed - show error
            esp_zb_scheduler_alarm((esp_zb_callback_t)bdb_start_top_level_commissioning_cb, 
                                  ESP_ZB_BDB_MODE_NETWORK_STEERING, 1000);
        }
        break;
        
    case ESP_ZB_ZDO_SIGNAL_LEAVE:
        ESP_LOGW(TAG, "[LEAVE] Device left the network");
        status_led_stop_blink();  // Stop any blinking
        led_set_status(LED_COLOR_ORANGE);  // Left network
        esp_zb_scheduler_alarm((esp_zb_callback_t)bdb_start_top_level_commissioning_cb,
                              ESP_ZB_BDB_MODE_NETWORK_STEERING, 30000);
        break;
        
    default:
        /* Quiet down frequent network maintenance signals */
        if (sig_type == ESP_ZB_NWK_SIGNAL_NO_ACTIVE_LINKS_LEFT ||      // 0x18
            sig_type == ESP_ZB_NLME_STATUS_INDICATION ||               // 0x32
            sig_type == ESP_ZB_ZDO_DEVICE_UNAVAILABLE) {               // 0x3c
            ESP_LOGD(TAG, "[ZDO] Signal: %s (0x%x), status: %s", 
                    esp_zb_zdo_signal_to_string(sig_type), sig_type,
                    esp_err_to_name(err_status));
        } else {
            ESP_LOGI(TAG, "[ZDO] Signal: %s (0x%x), status: %s", 
                    esp_zb_zdo_signal_to_string(sig_type), sig_type,
                    esp_err_to_name(err_status));
        }
        break;
    }
}
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
void app_main(void)
{
    esp_zb_platform_config_t config = {
        .radio_config = ESP_ZB_DEFAULT_RADIO_CONFIG(),
        .host_config = ESP_ZB_DEFAULT_HOST_CONFIG(),
    };
    
    ESP_ERROR_CHECK(nvs_flash_init());
    
    /* Initialize settings from NVS early so they're available for cluster creation */
    ESP_LOGI(TAG, "Loading settings from NVS...");
    settings_init();
    
    ESP_ERROR_CHECK(esp_zb_platform_config(&config));
    
    /* OTA validation */
    ota_validation_start();
    ota_validation_hw_init_ok();
    ota_validation_zigbee_init_ok();
    
    xTaskCreate(esp_zb_task, "Zigbee_main", 4096, NULL, 5, NULL);
}

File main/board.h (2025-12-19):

/* Board-specific hardware configuration for ESP32-C6 Supermini
 * GPIO pin definitions for sensors, LEDs, and peripherals
 */
#pragma once

#include "driver/gpio.h"

/* I2C Bus Configuration - Dual Bus Setup
 * Bus 0: SCD4x (CO2) + SGP41 (VOC/NOx) - Self-heating sensors
 * Bus 1: SHT4x (Temp/Humidity) + DPS368 (Pressure) - Precision environmental sensors
 */
#define I2C_BUS0_SDA_GPIO    GPIO_NUM_14  /* I2C Bus 0 SDA */
#define I2C_BUS0_SCL_GPIO    GPIO_NUM_15  /* I2C Bus 0 SCL */
#define I2C_BUS1_SDA_GPIO    GPIO_NUM_3   /* I2C Bus 1 SDA */
#define I2C_BUS1_SCL_GPIO    GPIO_NUM_4   /* I2C Bus 1 SCL */
#define I2C_MASTER_FREQ_HZ   100000       /* 100kHz I2C clock */

/* RGB LED configuration (SK6812/WS2812B) - 5 LEDs in daisy-chain configuration
 * All LEDs connected in series on a single GPIO with SN74AHCT1G125 buffer
 * LED order in chain: CO2 -> VOC -> NOx -> Humidity -> Status
 */
#ifndef LED_STRIP_GPIO
#define LED_STRIP_GPIO GPIO_NUM_2   /* Single GPIO for all LEDs (through SN74AHCT1G125 buffer) */
#endif

#define LED_STRIP_NUM_LEDS 5  /* Total number of LEDs in the chain */

/* LED positions in the daisy-chain (0-indexed) */
#define LED_CHAIN_INDEX_CO2      0  /* First LED: CO2 level indicator */
#define LED_CHAIN_INDEX_VOC      1  /* Second LED: VOC Index indicator */
#define LED_CHAIN_INDEX_NOX      2  /* Third LED: NOx Index indicator */
#define LED_CHAIN_INDEX_HUMIDITY 3  /* Fourth LED: Humidity level indicator */
#define LED_CHAIN_INDEX_STATUS   4  /* Fifth LED: Zigbee network status indicator */

/* Fan Control Configuration (PWM 4-wire fan with TACH feedback)
 * Circuit: IRLML6344TRPBF N-MOSFET + N5819HW1-7-F Schottky diode
 * Fan: 5V PWM fan with tachometer output
 */
#define FAN_POWER_GPIO      GPIO_NUM_5   /* Fan power control via N-MOSFET (ON/OFF) */
#define FAN_PWM_GPIO        GPIO_NUM_6   /* PWM speed control output (0-100%) */
#define FAN_TACH_GPIO       GPIO_NUM_7   /* Tachometer pulse input (RPM monitoring) */
#define FAN_PWM_FREQ_HZ     25000        /* 25 kHz PWM frequency (standard for PC fans) */

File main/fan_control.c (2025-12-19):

/*
 * Fan Control Driver Implementation for Aeris_Lite
 * 
 * PWM speed control and RPM monitoring using ESP32-C6 LEDC and Pulse Counter
 */

#include "fan_control.h"
#include "board.h"
#include "driver/ledc.h"
#include "driver/gpio.h"
#include "driver/pulse_cnt.h"
#include "esp_log.h"
#include "freertos/FreeRTOS.h"
#include "freertos/task.h"

static const char *TAG = "FAN";

/* LEDC configuration for PWM */
#define FAN_PWM_TIMER       LEDC_TIMER_0
#define FAN_PWM_CHANNEL     LEDC_CHANNEL_0
#define FAN_PWM_MODE        LEDC_LOW_SPEED_MODE
#define FAN_PWM_RESOLUTION  LEDC_TIMER_8_BIT  /* 0-255 duty cycle */

/* Fan configuration */
#define FAN_MIN_SPEED_PERCENT   20   /* Minimum speed to reliably start fan */
#define FAN_RPM_RUNNING_THRESH  100  /* RPM threshold to consider fan "running" */
#define FAN_PULSES_PER_REV      2    /* Standard for 4-wire fans */

/* Module state */
static pcnt_unit_handle_t pcnt_unit = NULL;
static bool fan_initialized = false;
static bool fan_power_enabled = false;
static uint8_t fan_current_speed = 0;
static uint32_t fan_last_rpm = 0;

/**
 * @brief Initialize fan power control GPIO (MOSFET driver)
 */
static esp_err_t fan_power_init(void)
{
    gpio_config_t io_conf = {
        .pin_bit_mask = (1ULL << FAN_POWER_GPIO),
        .mode = GPIO_MODE_OUTPUT,
        .pull_down_en = GPIO_PULLDOWN_ENABLE,
        .pull_up_en = GPIO_PULLUP_DISABLE,
        .intr_type = GPIO_INTR_DISABLE,
    };
    esp_err_t ret = gpio_config(&io_conf);
    if (ret != ESP_OK) {
        ESP_LOGE(TAG, "Failed to configure fan power GPIO: %s", esp_err_to_name(ret));
        return ret;
    }
    
    /* Start with fan off */
    gpio_set_level(FAN_POWER_GPIO, 0);
    ESP_LOGI(TAG, "Fan power control initialized on GPIO%d", FAN_POWER_GPIO);
    
    return ESP_OK;
}

/**
 * @brief Initialize PWM for fan speed control
 */
static esp_err_t fan_pwm_init(void)
{
    /* Configure LEDC timer */
    ledc_timer_config_t timer_conf = {
        .speed_mode = FAN_PWM_MODE,
        .duty_resolution = FAN_PWM_RESOLUTION,
        .timer_num = FAN_PWM_TIMER,
        .freq_hz = FAN_PWM_FREQ_HZ,
        .clk_cfg = LEDC_AUTO_CLK,
    };
    esp_err_t ret = ledc_timer_config(&timer_conf);
    if (ret != ESP_OK) {
        ESP_LOGE(TAG, "Failed to configure PWM timer: %s", esp_err_to_name(ret));
        return ret;
    }
    
    /* Configure LEDC channel */
    ledc_channel_config_t channel_conf = {
        .gpio_num = FAN_PWM_GPIO,
        .speed_mode = FAN_PWM_MODE,
        .channel = FAN_PWM_CHANNEL,
        .timer_sel = FAN_PWM_TIMER,
        .duty = 0,  /* Start at 0% */
        .hpoint = 0,
    };
    ret = ledc_channel_config(&channel_conf);
    if (ret != ESP_OK) {
        ESP_LOGE(TAG, "Failed to configure PWM channel: %s", esp_err_to_name(ret));
        return ret;
    }
    
    ESP_LOGI(TAG, "Fan PWM initialized on GPIO%d at %d Hz", FAN_PWM_GPIO, FAN_PWM_FREQ_HZ);
    
    return ESP_OK;
}

/**
 * @brief Initialize tachometer pulse counter
 */
static esp_err_t fan_tach_init(void)
{
    /* Configure TACH GPIO with pull-up (open-drain output from fan) */
    gpio_config_t io_conf = {
        .pin_bit_mask = (1ULL << FAN_TACH_GPIO),
        .mode = GPIO_MODE_INPUT,
        .pull_up_en = GPIO_PULLUP_ENABLE,
        .pull_down_en = GPIO_PULLDOWN_DISABLE,
        .intr_type = GPIO_INTR_DISABLE,
    };
    esp_err_t ret = gpio_config(&io_conf);
    if (ret != ESP_OK) {
        ESP_LOGE(TAG, "Failed to configure TACH GPIO: %s", esp_err_to_name(ret));
        return ret;
    }
    
    /* Configure pulse counter unit */
    pcnt_unit_config_t unit_config = {
        .high_limit = 20000,  /* High enough for fast fans */
        .low_limit = 0,
    };
    ret = pcnt_new_unit(&unit_config, &pcnt_unit);
    if (ret != ESP_OK) {
        ESP_LOGE(TAG, "Failed to create pulse counter unit: %s", esp_err_to_name(ret));
        return ret;
    }
    
    /* Configure pulse counter channel */
    pcnt_chan_config_t chan_config = {
        .edge_gpio_num = FAN_TACH_GPIO,
        .level_gpio_num = -1,
    };
    pcnt_channel_handle_t pcnt_chan = NULL;
    ret = pcnt_new_channel(pcnt_unit, &chan_config, &pcnt_chan);
    if (ret != ESP_OK) {
        ESP_LOGE(TAG, "Failed to create pulse counter channel: %s", esp_err_to_name(ret));
        pcnt_del_unit(pcnt_unit);
        pcnt_unit = NULL;
        return ret;
    }
    
    /* Count on falling edge (standard for TACH signals) */
    ret = pcnt_channel_set_edge_action(pcnt_chan,
                                        PCNT_CHANNEL_EDGE_ACTION_INCREASE,
                                        PCNT_CHANNEL_EDGE_ACTION_HOLD);
    if (ret != ESP_OK) {
        ESP_LOGE(TAG, "Failed to set edge action: %s", esp_err_to_name(ret));
        pcnt_del_unit(pcnt_unit);
        pcnt_unit = NULL;
        return ret;
    }
    
    /* Enable and start counter */
    ret = pcnt_unit_enable(pcnt_unit);
    if (ret != ESP_OK) {
        ESP_LOGE(TAG, "Failed to enable pulse counter: %s", esp_err_to_name(ret));
        pcnt_del_unit(pcnt_unit);
        pcnt_unit = NULL;
        return ret;
    }
    
    ret = pcnt_unit_clear_count(pcnt_unit);
    if (ret == ESP_OK) {
        ret = pcnt_unit_start(pcnt_unit);
    }
    
    if (ret != ESP_OK) {
        ESP_LOGE(TAG, "Failed to start pulse counter: %s", esp_err_to_name(ret));
        pcnt_unit_disable(pcnt_unit);
        pcnt_del_unit(pcnt_unit);
        pcnt_unit = NULL;
        return ret;
    }
    
    ESP_LOGI(TAG, "Fan TACH monitoring initialized on GPIO%d", FAN_TACH_GPIO);
    
    return ESP_OK;
}

esp_err_t fan_init(void)
{
    if (fan_initialized) {
        ESP_LOGW(TAG, "Fan control already initialized");
        return ESP_OK;
    }
    
    ESP_LOGI(TAG, "Initializing fan control system...");
    
    /* Initialize power control */
    esp_err_t ret = fan_power_init();
    if (ret != ESP_OK) {
        return ret;
    }
    
    /* Initialize PWM */
    ret = fan_pwm_init();
    if (ret != ESP_OK) {
        return ret;
    }
    
    /* Initialize tachometer */
    ret = fan_tach_init();
    if (ret != ESP_OK) {
        ESP_LOGW(TAG, "TACH initialization failed, continuing without RPM monitoring");
        /* Non-fatal - continue without RPM monitoring */
    }
    
    fan_initialized = true;
    fan_power_enabled = false;
    fan_current_speed = 0;
    fan_last_rpm = 0;
    
    ESP_LOGI(TAG, "Fan control system initialized successfully");
    
    return ESP_OK;
}
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

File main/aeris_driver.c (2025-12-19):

/*
 * Aeris Air Quality Sensor Driver Implementation
 *
 * I2C communication with air quality sensors
 * Supports Temperature, Humidity, Pressure, VOC Index, and CO2 sensors
 */

#include "aeris_driver.h"
#include "board.h"
#include "fan_control.h"
#include "esp_log.h"
#include "string.h"
#include "freertos/FreeRTOS.h"
#include "freertos/task.h"
#include "driver/i2c_master.h"
#include "driver/uart.h"
#include "driver/gpio.h"

static const char *TAG = "AERIS_DRIVER";

/* SHT45 Commands */
#define SHT45_CMD_MEASURE_HIGH  0xFD  // Measure T & RH with high precision (8.2ms)
#define SHT45_CMD_MEASURE_MED   0xF6  // Measure T & RH with medium precision (4.5ms)
#define SHT45_CMD_MEASURE_LOW   0xE0  // Measure T & RH with low precision (1.7ms)
#define SHT45_CMD_SOFT_RESET    0x94  // Soft reset
#define SHT45_CMD_READ_SERIAL   0x89  // Read serial number

/* SHT45 timing constants (in ms) */
#define SHT45_MEASURE_TIME_MS   10    // Measurement duration for medium precision (4.5ms typical, 10ms for safety)
#define SHT45_RESET_TIME_MS     10    // Time after soft reset (datasheet says 1ms max, but add margin)

/* LPS22HB Register Addresses */
#define LPS22HB_WHO_AM_I        0x0F  // Device identification (should return 0xB1)
#define LPS22HB_CTRL_REG1       0x10  // Control register 1
#define LPS22HB_CTRL_REG2       0x11  // Control register 2
#define LPS22HB_CTRL_REG3       0x12  // Control register 3
#define LPS22HB_STATUS_REG      0x27  // Status register
#define LPS22HB_PRESS_OUT_XL    0x28  // Pressure output low byte
#define LPS22HB_PRESS_OUT_L     0x29  // Pressure output middle byte
#define LPS22HB_PRESS_OUT_H     0x2A  // Pressure output high byte
#define LPS22HB_TEMP_OUT_L      0x2B  // Temperature output low byte
#define LPS22HB_TEMP_OUT_H      0x2C  // Temperature output high byte

/* LPS22HB Constants */
#define LPS22HB_DEVICE_ID       0xB1  // WHO_AM_I expected value

/* SGP41 Commands */
#define SGP41_CMD_EXECUTE_CONDITIONING  0x2612  // Execute conditioning (10s)
#define SGP41_CMD_MEASURE_RAW_SIGNALS   0x2619  // Measure raw signals (50ms)
#define SGP41_CMD_EXECUTE_SELF_TEST     0x280E  // Execute self test (320ms)
#define SGP41_CMD_TURN_HEATER_OFF       0x3615  // Turn heater off (1ms)
#define SGP41_CMD_GET_SERIAL_NUMBER     0x3682  // Get serial number (1ms)

/* SGP41 timing constants (in ms) */
#define SGP41_CONDITIONING_TIME_MS      10
#define SGP41_MEASURE_TIME_MS           50
#define SGP41_SELFTEST_TIME_MS          320
#define SGP41_STARTUP_TIME_MS           170  // Time after power-on
#define SGP41_MIN_SAMPLING_INTERVAL_MS  1000 // Minimum 1Hz sampling rate (datasheet requirement)

/* SCD40 Commands */
#define SCD40_CMD_START_PERIODIC_MEASUREMENT    0x21B1  // Start periodic measurement
#define SCD40_CMD_READ_MEASUREMENT              0xEC05  // Read measurement
#define SCD40_CMD_STOP_PERIODIC_MEASUREMENT     0x3F86  // Stop periodic measurement
#define SCD40_CMD_SET_TEMPERATURE_OFFSET        0x241D  // Set temperature offset
#define SCD40_CMD_GET_TEMPERATURE_OFFSET        0x2318  // Get temperature offset
#define SCD40_CMD_SET_SENSOR_ALTITUDE           0x2427  // Set sensor altitude
#define SCD40_CMD_GET_SENSOR_ALTITUDE           0x2322  // Get sensor altitude
#define SCD40_CMD_SET_AMBIENT_PRESSURE          0xE000  // Set ambient pressure
#define SCD40_CMD_PERFORM_FORCED_RECALIBRATION  0x362F  // Perform forced recalibration
#define SCD40_CMD_SET_AUTOMATIC_SELF_CALIB      0x2416  // Set automatic self-calibration
#define SCD40_CMD_GET_AUTOMATIC_SELF_CALIB      0x2313  // Get automatic self-calibration
#define SCD40_CMD_GET_DATA_READY_STATUS         0xE4B8  // Get data ready status
#define SCD40_CMD_PERSIST_SETTINGS              0x3615  // Persist settings
#define SCD40_CMD_GET_SERIAL_NUMBER             0x3682  // Get serial number
#define SCD40_CMD_PERFORM_SELF_TEST             0x3639  // Perform self test
#define SCD40_CMD_PERFORM_FACTORY_RESET         0x3632  // Perform factory reset
#define SCD40_CMD_REINIT                        0x3646  // Re-initialization

/* SCD40 timing constants (in ms) */
#define SCD40_MEASUREMENT_INTERVAL_MS   5000   // Measurement interval (5 seconds)
#define SCD40_INITIAL_STARTUP_MS        1000   // Initial startup time
#define SCD40_STOP_PERIODIC_MS          500    // Time to stop periodic measurement
#define SCD40_READ_MEASUREMENT_MS       1      // Time to read measurement

/* Current sensor state */
static aeris_sensor_state_t current_state = {
    .temperature_c = 25.0f,
    .humidity_percent = 50.0f,
    .pressure_hpa = 1013.25f,
    .voc_index = 100,
    .nox_index = 1,
    .voc_raw = 0,
    .nox_raw = 0,
    .co2_ppm = 400,
    .sensor_error = false,
    .error_text = ""
};

/* SHT45 sensor state */
static bool sht45_initialized = false;
static uint32_t sht45_serial_number = 0;

/* Temperature offset compensation for self-heating (in °C)
 * Positive value = sensor reads higher than actual, so we subtract
 * Typical value: 2.0 to 4.0°C depending on PCB layout and airflow */
static float temperature_offset_c = 0.0f;  // Default no offset (configure via Zigbee)

/* Humidity offset compensation (in %RH)
 * Positive value = sensor reads higher than actual, so we subtract
 * Typical value: 0 to 5% depending on conditions */
static float humidity_offset_percent = 0.0f;  // Default no offset

/* LPS22HB sensor state */
static bool lps22hb_initialized = false;

/* SGP41 sensor state */
static bool sgp41_initialized = false;
static uint64_t sgp41_serial_number = 0;
static TickType_t sgp41_last_measure_time = 0;

/* SCD40 sensor state */
static bool scd40_initialized = false;
static uint64_t scd40_serial_number = 0;

/* I2C master bus and device handles (new driver) */
static i2c_master_bus_handle_t i2c_bus0_handle = NULL;  // Bus 0: SCD4x + SGP41
static i2c_master_bus_handle_t i2c_bus1_handle = NULL;  // Bus 1: SHT4x + DPS368
static i2c_master_dev_handle_t sht45_dev_handle = NULL;
static i2c_master_dev_handle_t lps22hb_dev_handle = NULL;
static i2c_master_dev_handle_t sgp41_dev_handle = NULL;
static i2c_master_dev_handle_t scd40_dev_handle = NULL;

/**
 * @brief Calculate CRC8 for SHT45 and SGP41 (polynomial 0x31, init 0xFF)
 */
static uint8_t sensirion_crc8(const uint8_t *data, size_t len)
{
    uint8_t crc = 0xFF;
    for (size_t i = 0; i < len; i++) {
        crc ^= data[i];
        for (uint8_t bit = 0; bit < 8; bit++) {
            if (crc & 0x80) {
                crc = (crc << 1) ^ 0x31;
            } else {
                crc = (crc << 1);
            }
        }
    }
    return crc;
}
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

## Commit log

2025-11-03 Refactor Aeris Driver for Air Quality Sensors
    - Renamed and updated the Aeris driver files to reflect air quality sensor functionality instead of HVAC control.
    - Changed communication method from UART to I2C for sensor interaction.
    - Introduced new data structures and functions to handle temperature, humidity, pressure, PM, VOC Index, and CO2 readings.
    - Implemented initialization and reading functions for various air quality sensors.
    - Updated Zigbee integration to expose air quality sensor data as endpoints.
    - Removed obsolete HVAC-related code and definitions, focusing solely on air quality metrics.
2025-11-03 Add PMSA003A particulate matter sensor support with UART communication
2025-11-03 Add SGP41 VOC and NOx sensor support; update driver and README
2025-11-04 Add SCD40 CO2 sensor support; update driver and README
2025-11-04 Refactor Zigbee endpoint configuration and add OTA validation functions; implement all sensor endpoints with proper attribute updates
2025-11-05 feat: Enhance Zigbee Router with RGB LED Indicators for Air Quality
    - Updated README.md to include new features and detailed descriptions of RGB LED indicators.
    - Modified CMakeLists.txt to include RMT driver dependency for LED control.
    - Refactored aeris_driver.c to initialize RGB LED indicators and handle LED configuration via Zigbee.
    - Created led_indicator.c and led_indicator.h for managing RGB LED operations, including color settings based on air quality sensor readings.
    - Added support for configurable LED thresholds for CO2, VOC, PM2.5, and Humidity.
    - Implemented real-time visual feedback through 4 RGB LEDs, providing immediate status on air quality parameters.
    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
2025-11-05 feat: Implement individual LED control via bitmask and update related configurations
2025-11-05 feat: Add PMSA003A power management and polling interval configuration
2025-11-05 feat: Add Zigbee status LED support with blinking indication during network join
2025-11-15 feat: Update README to include new Status LED endpoint and enhance PM thresholds; refactor µg/m³ to µg/m3 for consistency
2025-11-15 Refactor doc structure for improved readability and maintainability
    [aeris.kicad_pcb, aeris.kicad_sch]
2025-11-17 Add symbol library for ESP32-C6FH4-SuperMini to the project and update project GPIOs
    [aeris.kicad_sch]
2025-11-19 PCB version 1.0 Update PIN assignment for better PCB routing
    [aeris-B_Cu.gbl, aeris-B_Mask.gbs, aeris-B_Paste.gbp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]
2025-11-20 Final update for PCB version 1.0 before manufacturing
2025-11-20 Update .gitignore to remove unecessary PCB files
2025-11-20 Fix paths in .gitignore for PCB backups and cache files
2025-12-02 feat: Implement WiFi WebSocket logging for real-time console output
    - Added WiFi logging functionality to broadcast logs over WebSocket.
    - Introduced configuration options in board.h for enabling/disabling logging and setting WiFi credentials.
    - Created wifi_log.c and wifi_log.h for handling WiFi connections and WebSocket communication.
    - Updated led_indicator.c to use a shared RMT channel for LED control.
    - Modified esp_zb_aeris.c to initialize WiFi logging during app startup.
    - Adjusted aeris_driver.h for I2C address corrections and driver inclusions.
    - Enhanced board.h with debug flags and WiFi logging configuration.
    - Cleaned up unnecessary code in esp_zb_aeris.c related to LED attribute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
    [aeris.kicad_pcb]
2025-12-02 fix: Update boot button and WiFi logging configurations for debugging
    [board.h, esp_zb_aeris.c]
2025-12-03 feat: Add temperature and humidity offset compensation, and LED brightness control
2025-12-03 Refactor PCB design and update sensor configurations
    - Changed footprint references for LED components to use the correct library.
    - Enhanced README with detailed sensor conversion formulas and calibration notes.
    - Updated aeris_driver.c to enforce minimum sampling intervals for SGP41 and SCD40 sensors.
    - Disabled automatic self-calibration for SCD40 to maintain stable CO2 baseline.
    - Adjusted LPS22HB sensor configuration to use one-shot mode for power savings.
    [aeris.kicad_pcb, aeris.kicad_sch]
2025-12-10 fix: Correct SHT45 measurement time and update brownout detection configuration
    [aeris_driver.c]
2025-12-18 Remove Plantower sensor
2025-12-18 refactor: Update README and code to reflect removal of PM1.0, PM2.5, and PM10 sensors; adjust LED configurations accordingly
2025-12-19 Rename PCB files
    [aeris-B_Cu.gbl, aeris-B_Mask.gbs, aeris-B_Paste.gbp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]
2025-12-19 PCVB : Work in progress
    [aeris-lite.kicad_pcb, aeris-lite.kicad_sch]
2025-12-19 Summary of Changes: Hardware Configuration (board.h & aeris_driver.h): I2C Bus 0: GPIO14 (SDA) + GPIO15 (SCL) → SCD4x (CO2) + SGP41 (VOC/NOx) I2C Bus 1: GPIO3 (SDA) + GPIO4 (SCL) → SHT4x (Temp/Humidi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
    [aeris_driver.c]
2025-12-19 feat: Implement fan control driver for Aeris_Lite
    - Added fan_control.c and fan_control.h to manage PWM speed control and RPM monitoring for a 5V 4-wire PWM fan.
    - Integrated GPIO configuration for fan power control and tachometer pulse counting.
    - Implemented functions for initializing the fan system, setting power and speed, retrieving RPM, and checking fan status.
    - Added adaptive control based on temperature and air quality sensor readings.
    - Defined fan operating modes and status structure for better management and monitoring.
    [aeris-lite.kicad_pcb, aeris-lite.kicad_sch]

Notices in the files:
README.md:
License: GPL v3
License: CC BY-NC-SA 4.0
